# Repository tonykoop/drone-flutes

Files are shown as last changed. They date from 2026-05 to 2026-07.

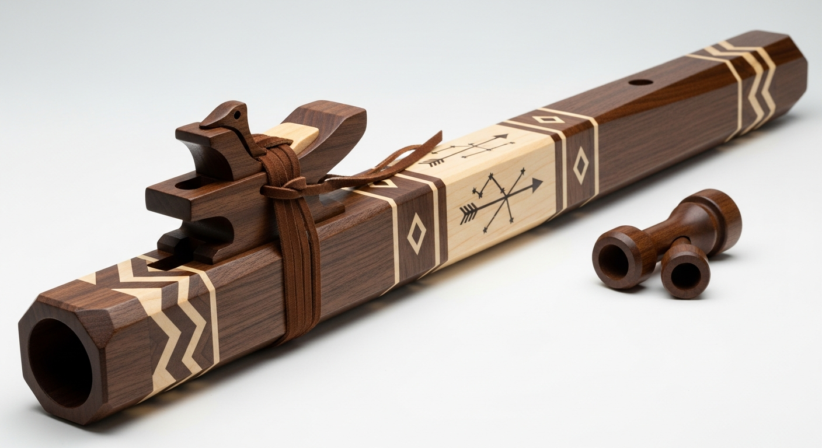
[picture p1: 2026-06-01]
images/hero-render.png

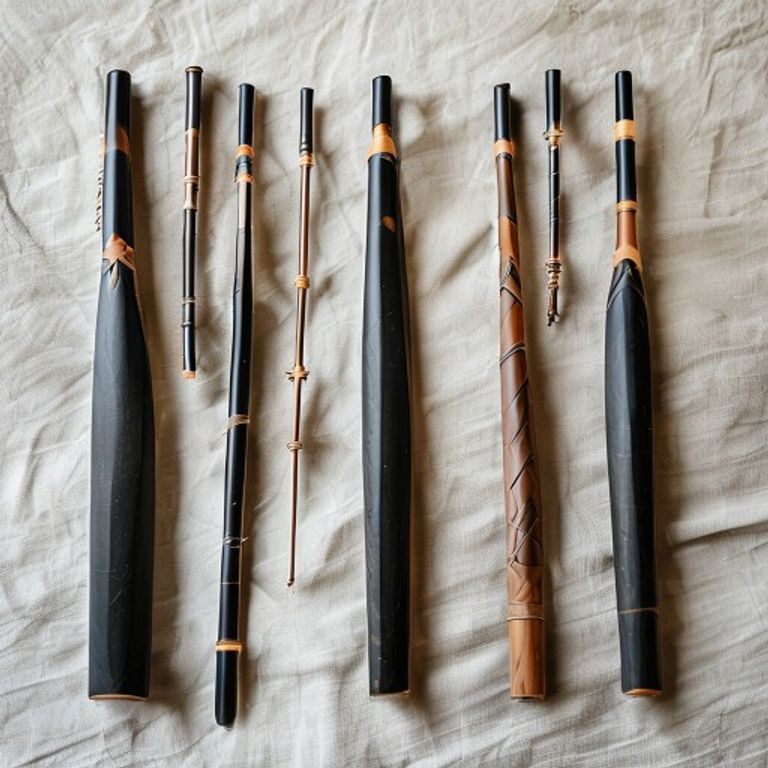
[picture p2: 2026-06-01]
images/family-group.png

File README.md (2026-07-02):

# Drone Flutes

A four-member family of Native American style drone flutes — Am, F#m, Em, Dm — built on Tony's open-pipe parametric design pipeline, with hybrid CNC + lathe + facet construction and Broinwood-style geometric CNC inlay in hard maple over walnut bodies. Each flute ships with three swappable drone blocks (unison, fifth-below, octave-below) so the player can change drone tuning without touching the melody side.

This is `DRN-FAM-001` in the catalog.

**Status:** L2 V5 build-packet candidate — DXF-first shop-handoff authority chain documented; acoustic body and drone-block DXF/CAD exports are still required before CNC routing (DXF-REV-001, FAB-BORE-009 blocked). All melody-tuning validation.csv rows are measurement-required pending first-article build.

> Aesthetic references: [Elemental Flutes gallery](https://elementalflutes.com/gallery) for the drone-flute form and [Broinwood](https://broinwood.com) for the inlay style. Engineering reference: the [`flutes`](https://github.com/tonykoop/flutes) repo for NAF K2 empirical corrections (150+ flute dataset).

Family overview

## What's in the box

```
.
├── Drone-Flutes-Design.xlsx           ← parametric source of truth (284 formulas)
├── Drone-Flutes-BOM-Build-Method.docx ← shop-floor build doc (v3-style companion)
├── design.md                          ← physics + family narrative
├── family-spec.csv                    ← row per family member, drives generators
├── bom.csv · sourcing.csv             ← what to buy, where, for how much
├── cut-list.csv · validation.csv      ← shop ops + tuning targets
├── dxf-shop-authority.md              ← DXF/CAD authority checklist and blockers
├── shop-validation-gates.csv          ← drone tuning, breath response, tolerance gates
├── visual-output-register.csv         ← drawing/inlay visual authority ledger
├── assembly-manual.md                 ← shop-floor cheat sheet
├── supplier-rfq.md                    ← 3 RFQ drafts ready to send
├── drawing-brief.md · visual-bom-brief.md
├── wolfram-starter.wl                 ← interactive Wolfram notebook
├── risks.md                           ← red-team failure-mode walk
├── capstone-deck.pptx                 ← recruiter / collaborator deck
├── print-packet.pdf                   ← shop-floor printable
├── site/index.html                    ← recruiter-facing static site
├── drawings/                          ← per-key SVG drawings + assembly + family-overview
├── inlay-patterns/{Am,Fsharpm,Em,Dm}/ ← 16 DXF + 16 SVG inlay patterns
├── sw-reference/                      ← SolidWorks master layout reference
├── cad/drone-flutes.scad              ← bore + tone-hole-schedule envelope master (pending_measurement; duct/fipple out of scope)
├── cnc/, images/, data/               ← placeholders for binary assets
├── evolution/                         ← Stage-0 evolution-pipeline intake (master manifest, design intent, revisions)
└── capstone-manifest.json             ← machine-readable manifest of everything above
```

## How it's built

1. **Excel `Master_Inputs` sheet** is the single edit surface for every dimension. Blue cells are inputs; black cells are formulas. Names match the SolidWorks global variables exactly.
2. **SolidWorks** reads from Excel via a linked design table (configurations: Am, F#m, Em, Dm). Master sketch on the Front plane drives every other sketch via convert-entities and pierce relations.
3. **CNC G-code** is generated in V-Carve from SolidWorks DXFs. Bore profile (1/4 downcut) → SAC pocket → splitting edge (1/16 upcut climb) → octagon facet pass (1/2 downcut, V-block jig) → inlay pockets (1/16 upcut) → finger holes (drill press, brad-point bits).
4. **Lathe** turns each glued blank to `body_OD_round` between centers; faceting then brings it to `body_OD_flat`.
5. **Drone blocks** are lathe-turned with a 0.75" tenon at 0.005" slip-fit clearance. Three blocks per flute (U / 5 / 8) for swappable drone tuning.

## DXF/shop authority boundary

The current repo has decorative inlay DXFs under `inlay-patterns/`, but no
released body, bore, finger-hole, SAC/window, drone-block, socket, or fixture
DXF/CAD files in the checkout. Use `dxf-shop-authority.md` as the shop handoff
checklist before cutting acoustic geometry. The inlay DXFs may guide decorative
inlay layout only; they do not control tuning, bore geometry, tone-hole
placement, breath response, drone-block fit, or flute-body tolerances.

## Family table

| Member | Key | f₀ (Hz) | bore_ID | L_total | Chamber:bore |
|---|---|---|---|---|---|
| DRN-Am  | Am  | 440.000 | 0.750" | 21.97 in | 20.4 |
| DRN-Fsm | F#m | 369.994 | 0.875" | 24.99 in | 21.0 |
| DRN-Em  | Em  | 329.628 | 1.000" | 27.23 in | 20.7 |
| DRN-Dm  | Dm  | 293.665 | 1.125" | 29.82 in | 20.8 |

All chamber:bore ratios sit in Tony's 17–21 sweet spot. Hole positions follow `pos_from_foot = L_acoustic_corrected × (1 − f₀/f_hole)` with K2 piecewise correction by bore size.

## Sister repos

This packet is part of Tony's open-pipe woodwind cluster. Cross-references:

- [`flutes`](https://github.com/tonykoop/flutes) — NAF family + K2 corrections (engineering reference)
- [`fujara`](https://github.com/tonykoop/fujara) — Slovak overtone flute (related physics)
- [`transverse-flute`](https://github.com/tonykoop/transverse-flute) — slip-cast transverse flute family
- [`shakuhachi`](https://github.com/tonykoop/shakuhachi)

For the cross-cluster catalog see `instrument-maker-v4` skill `references/repo-relationships.yaml`.

## Skill index used

- [instrument-maker-v4](https://...) — orchestrator + specialist sub-agents (acoustician, manufacturing-planner, documentarian, verifier, red-team)
- [xlsx](https://...) — Drone-Flutes-Design.xlsx
- [docx](https://...) — SolidWorks reference + BOM doc
- [pptx](https://...) — capstone-deck.pptx
- [pdf](https://...) — print-packet.pdf

## Roadmap

- [x] Excel design workbook with 284 formulas and 6 sheets
- [x] SolidWorks reference doc with global variables + design table setup
- [x] BOM + Build Method doc (v3-style companion)
- [x] CNC inlay patterns: 4 keys × 4 patterns × 2 formats = 32 files
- [x] v4 deliverables: design.md, family-spec, BOM/sourcing/cut/validation CSVs, assembly manual, RFQ, briefs, Wolfram starter, risks, capstone deck, print packet, site
- [ ] Build flute 1 (F#m) and tune-validate
- [ ] Update K2 corrections from measured data via `record_measurement.py`
- [ ] Photograph all 4 finished flutes for hero image
- [ ] Publish `site/` to GitHub Pages

## License

See [LICENSE](LICENSE).

## Contact

Tony Koop · tonykoop@gmail.com

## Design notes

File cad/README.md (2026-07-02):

# CAD Starter Notes

`drone-flutes.scad` is the first parametric master for this repo. Authority:
`pending_measurement` — see `visual-output-register.csv` CAD-001 and
`mcp-session-log.md`. No placeholder existed before this pass; there was no
`cad/` directory in the checkout prior to 2026-07-01.

Scope: melody-bore envelope, parallel drone-bore envelope, octagonal body
facet reference envelope, and the six pentatonic-minor tone-hole positions
(equation-driven from `design.md`'s governing model, the same way fret slots
are equation-driven elsewhere in this cluster). All four family members
(Am, F#m, Em, Dm) are selectable via the `member` parameter and each renders
clean in OpenSCAD.

Out of scope (per `dxf-shop-authority.md` and the woodwind addendum): SAC
chamber, splitting-edge/window profile, bird-block/flue-gap voicing, tone-hole
undercut/counterbore, and drone-socket tenon fit. These are hand-refined,
tuning-sensitive regions and are not modeled here — do not treat this master
as a substitute for the reviewed body/bore/tone-hole/drone-block DXF or CAD
exports that `dxf-shop-authority.md` still lists as missing (DXF-REV-001,
FAB-BORE-009 remain blocked).

Known open items carried in the header comment of the .scad itself:
- Melody-bore-to-drone-bore centerline offset is not in `family-spec.csv` or
  `design.md` — exposed as a top-level TBD/assumption parameter, not fact.
- Tone-hole diameter per member is inferred from `bom.csv` row 3.5's four
  brad-point sizes in ascending-bore order; the source row does not tag each
  size to a member, so treat this as an assumption pending review.

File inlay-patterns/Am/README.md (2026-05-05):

# Am drone flute — inlay artwork

Inlay files are sized to fit ONE facet of the Am flute. Eight identical bands wrap around the body (one per facet); the feature panel goes on a single chosen facet.

## Per-facet dimensions (this key)

| Item | Value |
|---|---|
| facet_side_length | 0.497 in |
| facet_inset | 0.100 in (each side) |
| inlay_band_width | 0.297 in |
| band_height | 0.500 in |
| feature_panel_width | 0.297 in |
| feature_panel_height | 7.029 in |
| L_total (full flute) | 21.967 in |

## Files

| File | Purpose | Pocket depth |
|---|---|---|
| `band1_chevron.svg` / `.dxf` | Lowest band (15% from foot) — chevron pattern | 0.060 in |
| `band2_chevron.svg` / `.dxf` | Center band (50%) — chevron pattern | 0.060 in |
| `band3_diamond.svg` / `.dxf` | Upper band (82%, just below bird) — diamond pattern | 0.060 in |
| `feature_constellation.svg` / `.dxf` | Feature panel (one facet, between band2 & band3) | 0.080 in |

Plug stock = 1/16" hard maple. Plug profile is the same DXF — V-Carve uses an inside offset of -0.001" for the pocket and outside offset of +0.0010" for the plug to create a 0.002" interference fit.

## DXF layers

- `POCKET_OUTLINE` — the rectangular pocket boundary (cut on profile pass)
- `CHEVRON` / `DIAMOND` / `STARS` / `ARROW` — engraved or cut-through detail lines
- `GUIDE` — visual reference only; do NOT machine

## Origin convention

DXFs anchor at (0,0) bottom-left so they import directly into V-Carve at the band y-offset given by Inlay_Layout sheet in the Excel workbook.

## CNC strategy

Use 1/16" upcut spiral. Spindle 18000 rpm, feed 60 ipm, plunge 20 ipm. Run pocket pass first; do plug profile cut on a separate fixture using maple stock.

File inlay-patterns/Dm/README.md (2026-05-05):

# Dm drone flute — inlay artwork

Inlay files are sized to fit ONE facet of the Dm flute. Eight identical bands wrap around the body (one per facet); the feature panel goes on a single chosen facet.

## Per-facet dimensions (this key)

| Item | Value |
|---|---|
| facet_side_length | 0.652 in |
| facet_inset | 0.100 in (each side) |
| inlay_band_width | 0.452 in |
| band_height | 0.500 in |
| feature_panel_width | 0.452 in |
| feature_panel_height | 9.544 in |
| L_total (full flute) | 29.824 in |

## Files

| File | Purpose | Pocket depth |
|---|---|---|
| `band1_chevron.svg` / `.dxf` | Lowest band (15% from foot) — chevron pattern | 0.060 in |
| `band2_chevron.svg` / `.dxf` | Center band (50%) — chevron pattern | 0.060 in |
| `band3_diamond.svg` / `.dxf` | Upper band (82%, just below bird) — diamond pattern | 0.060 in |
| `feature_constellation.svg` / `.dxf` | Feature panel (one facet, between band2 & band3) | 0.080 in |

Plug stock = 1/16" hard maple. Plug profile is the same DXF — V-Carve uses an inside offset of -0.001" for the pocket and outside offset of +0.0010" for the plug to create a 0.002" interference fit.

## DXF layers

- `POCKET_OUTLINE` — the rectangular pocket boundary (cut on profile pass)
- `CHEVRON` / `DIAMOND` / `STARS` / `ARROW` — engraved or cut-through detail lines
- `GUIDE` — visual reference only; do NOT machine

## Origin convention

DXFs anchor at (0,0) bottom-left so they import directly into V-Carve at the band y-offset given by Inlay_Layout sheet in the Excel workbook.

## CNC strategy

Use 1/16" upcut spiral. Spindle 18000 rpm, feed 60 ipm, plunge 20 ipm. Run pocket pass first; do plug profile cut on a separate fixture using maple stock.

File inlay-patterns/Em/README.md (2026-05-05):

# Em drone flute — inlay artwork

Inlay files are sized to fit ONE facet of the Em flute. Eight identical bands wrap around the body (one per facet); the feature panel goes on a single chosen facet.

## Per-facet dimensions (this key)

| Item | Value |
|---|---|
| facet_side_length | 0.601 in |
| facet_inset | 0.100 in (each side) |
| inlay_band_width | 0.401 in |
| band_height | 0.500 in |
| feature_panel_width | 0.401 in |
| feature_panel_height | 8.712 in |
| L_total (full flute) | 27.225 in |

## Files

| File | Purpose | Pocket depth |
|---|---|---|
| `band1_chevron.svg` / `.dxf` | Lowest band (15% from foot) — chevron pattern | 0.060 in |
| `band2_chevron.svg` / `.dxf` | Center band (50%) — chevron pattern | 0.060 in |
| `band3_diamond.svg` / `.dxf` | Upper band (82%, just below bird) — diamond pattern | 0.060 in |
| `feature_constellation.svg` / `.dxf` | Feature panel (one facet, between band2 & band3) | 0.080 in |

Plug stock = 1/16" hard maple. Plug profile is the same DXF — V-Carve uses an inside offset of -0.001" for the pocket and outside offset of +0.0010" for the plug to create a 0.002" interference fit.

## DXF layers

- `POCKET_OUTLINE` — the rectangular pocket boundary (cut on profile pass)
- `CHEVRON` / `DIAMOND` / `STARS` / `ARROW` — engraved or cut-through detail lines
- `GUIDE` — visual reference only; do NOT machine

## Origin convention

DXFs anchor at (0,0) bottom-left so they import directly into V-Carve at the band y-offset given by Inlay_Layout sheet in the Excel workbook.

## CNC strategy

Use 1/16" upcut spiral. Spindle 18000 rpm, feed 60 ipm, plunge 20 ipm. Run pocket pass first; do plug profile cut on a separate fixture using maple stock.

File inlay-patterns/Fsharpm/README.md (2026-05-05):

# F#m drone flute — inlay artwork

Inlay files are sized to fit ONE facet of the F#m flute. Eight identical bands wrap around the body (one per facet); the feature panel goes on a single chosen facet.

## Per-facet dimensions (this key)

| Item | Value |
|---|---|
| facet_side_length | 0.549 in |
| facet_inset | 0.100 in (each side) |
| inlay_band_width | 0.349 in |
| band_height | 0.500 in |
| feature_panel_width | 0.349 in |
| feature_panel_height | 7.996 in |
| L_total (full flute) | 24.987 in |

## Files

| File | Purpose | Pocket depth |
|---|---|---|
| `band1_chevron.svg` / `.dxf` | Lowest band (15% from foot) — chevron pattern | 0.060 in |
| `band2_chevron.svg` / `.dxf` | Center band (50%) — chevron pattern | 0.060 in |
| `band3_diamond.svg` / `.dxf` | Upper band (82%, just below bird) — diamond pattern | 0.060 in |
| `feature_constellation.svg` / `.dxf` | Feature panel (one facet, between band2 & band3) | 0.080 in |

Plug stock = 1/16" hard maple. Plug profile is the same DXF — V-Carve uses an inside offset of -0.001" for the pocket and outside offset of +0.0010" for the plug to create a 0.002" interference fit.

## DXF layers

- `POCKET_OUTLINE` — the rectangular pocket boundary (cut on profile pass)
- `CHEVRON` / `DIAMOND` / `STARS` / `ARROW` — engraved or cut-through detail lines
- `GUIDE` — visual reference only; do NOT machine

## Origin convention

DXFs anchor at (0,0) bottom-left so they import directly into V-Carve at the band y-offset given by Inlay_Layout sheet in the Excel workbook.

## CNC strategy

Use 1/16" upcut spiral. Spindle 18000 rpm, feed 60 ipm, plunge 20 ipm. Run pocket pass first; do plug profile cut on a separate fixture using maple stock.

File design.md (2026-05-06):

# Drone Flute Family — Parametric Design (v4)

**Packet:** DRN-FAM-001
**Family:** open-pipe (Native American Flute lineage; drone-flute variant)
**Pipeline:** cnc-lathe (hybrid: split-body CNC + lathe round + CNC facet)
**Status:** in-progress
**Sisters:** [flutes](https://github.com/tonykoop/flutes), [fujara](https://github.com/tonykoop/fujara), [transverse-flute](https://github.com/tonykoop/transverse-flute), [shakuhachi](https://github.com/tonykoop/shakuhachi)
**Done-bar reference:** `flutes` (NAF family with K2 corrections)
**Aesthetic references:** elementalflutes.com/gallery, broinwood.com (CNC inlay)
**Date:** 2026-05-05

## What this is

A four-member family of Native American style **drone flutes** (each flute has both a melodic side and a separate sustained-drone chamber sharing the same body). Keys: Am, F#m, Em, Dm. Bodies are walnut, inlay is hard maple. The drone block is **swappable** — three blocks ship per flute (unison, perfect fifth below, octave below) so the player can change the drone without retuning the melody side.

This is the same parametric workflow Tony uses for the rest of the open-pipe woodwinds (`flutes`, `fujara`, `transverse-flute`): an Excel `Master_Inputs` sheet with named global variables drives the `Design_Table`; SolidWorks reads from the same Excel via a linked design table; CNC G-code is generated in V-Carve from SolidWorks-exported DXFs.

## Governing model

Open-open pipe with end corrections and Tony's empirical NAF K2 bore-size correction.

```
f = c / (2 · L_eff)
L_eff = L_acoustic_corrected = (c / (2 · f)) · (1 + K2(bore_ID))
L_bore_physical = L_acoustic_corrected − 2 · k_end · (bore_ID / 2)
```

- `c` = 13,552 in/s at 68°F
- `k_end` = 0.6 (open-end correction multiplier, applied at each open end)
- `K2(bore_ID)` is a piecewise lookup: −2.0 % for bore < 0.75 in, −0.7 % for 0.75–0.875, +0.4 % for 0.875–1.0, +0.7 % for 1.0–1.125, +1.3 % for ≥ 1.125 in. Source: 150+ NAF measurements (Tony's empirical dataset).

Hole positions (from foot, m3 closest to foot, octave farthest):

```
pos_from_foot = L_acoustic_corrected · (1 − f_fundamental / f_hole)
```

Pentatonic minor scale (NAF Mode 1/4): semitone offsets `[+3, +5, +7, +8, +10, +12]` from the fundamental.

The drone chamber is a separate parallel bore in the same body; it has its own `bore_ID`, its own K2 correction, and its own `L_acoustic`. The drone block tenon-fits into a socket at the foot end; three blocks per flute provide unison / fifth-below / octave-below tunings via different cavity lengths.

## Family scaling law

For a given pitch class (minor) and same drone-offset configuration, all member dimensions follow the open-pipe relationship `L ∝ 1/f`. Choosing bore_ID per key keeps the chamber-to-bore ratio inside Tony's 17–21 sweet spot (denser air column for lower keys, narrower bore for higher keys).

| Member | Key | Fund. (Hz) | Bore ID | L_total | Chamber:bore |
|---|---|---|---|---|---|
| DRN-Am  | Am  | 440.0 | 0.750" | 21.97 in | 20.4 |
| DRN-Fsm | F#m | 370.0 | 0.875" | 24.99 in | 21.0 |
| DRN-Em  | Em  | 329.6 | 1.000" | 27.23 in | 20.7 |
| DRN-Dm  | Dm  | 293.7 | 1.125" | 29.82 in | 20.8 |

See `family-spec.csv` for the row-per-member spec the auto-generators read.

## Parametric design surface

Source of truth for all numbers: **`Drone-Flutes-Design.xlsx`** (Master_Inputs sheet). Blue cells are user-editable inputs; black cells are formulas. SolidWorks reads from the Design_Table sheet via the linked design table — see `sw-reference/Drone-Flutes-SolidWorks-MasterLayout.docx`.

Key inputs (edit these to retarget the family):

- `c_speed_of_sound` (in/s) — adjust for shop temperature
- `A4_reference` (Hz) — concert pitch; 440 by default, can change to 432
- `MIDI_note` per column — defines each member's fundamental
- `bore_ID` per column — drives K2 and chamber:bore ratio
- `drone_offset_st` — global; flips all four flutes between unison/5th/octave drones
- `n_facets` — octagon by default; can change to hex (6) or dodecagon (12)
- Inlay parameters — band positions, depths, plug oversize

## Construction summary

Hybrid build:

1. **Split-body CNC** — bandsaw the blank in half along the long axis, route the bore profile and SAC pocket on each half, glue back. This is the only practical way to put a precision bore in a long blank with the ShopBot.
2. **Lathe rounding** — turn glued blank to `body_OD_round` (which includes a `facet_allowance` for the next step).
3. **CNC faceting** — V-block jig, eight 22.5° rotations, flatten each facet on the ShopBot to bring `body_OD_flat` to spec. This produces eight flat faces for inlay.
4. **CNC inlay** — chevron (band 1, 2), diamond (band 3), constellation+arrow (feature panel) per `inlay-patterns/{key}/`.
5. **Drone block set** — three lathe-turned blocks per flute (unison/5/8). Tenon engagement length 0.75", 0.005" slip-fit clearance.

## Validation strategy

Each finished flute is tuned with a chromatic tuner against the predicted frequencies in `validation.csv`. Cents error is recorded; deviations >5 cents trigger a hole-recutting decision (file the foot edge to lower, fill the bird edge to raise). Measured data feeds back into `validation.csv` and through `record_measurement.py` into Tony's per-family corrections database (eventually).

## Open assumptions

- A=440 reference. Change `A4_reference` for 432 or HIPP tunings.
- 68°F shop reference. The walnut-glue cure window assumes this.
- Octagon (8 facets). The same workbook supports 6 or 12 by changing `n_facets`.
- Walnut + maple as the wood pair. `Wood_Library` sheet lists alternates with E, ρ, Janka.
- Single concert-pitch tuning for all four flutes. Could split-tune (e.g., F#m and Dm at A=440 for solo, Em and Am at A=432 for ensemble work).

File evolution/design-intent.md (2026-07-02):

# Design Intent — drone-flutes rev A

- Master CAD: `cad/drone-flutes.scad` (sha256: 05f84ff9b06209cb90c3cb4582ba9f86a4075b30f41d5fecbc404bded7124ddd), driven by `family-spec.csv` (sha256: 1cfbed45703db40fa902f2bde1a24349374f9bfefdf9ba2f1b1fe5c1240d1253) and `Drone-Flutes-Design.xlsx` (sha256: d3b784c738a0f81cb7581b918f8eaa2f04b11650797b9905257d2063148a2dca)
- Function: A four-member family of Native American style drone flutes (Am, F#m, Em, Dm) — hybrid CNC + lathe + facet construction, hard maple inlay over walnut bodies. Each flute has a melody bore (open-open pipe, six pentatonic-minor finger holes) and a separate parallel drone chamber fed by one of three swappable tenon-fit drone blocks (unison / fifth-below / octave-below), so drone tuning can change without retuning the melody side.
- Environment: player-breath-driven open-pipe woodwind; walnut body is a solid-wood plate/tube assembly sensitive to humidity and glue-line integrity (risks.md S-1). Shop reference temperature 68°F (design.md).
- Target qty: 1 prototype (F#m first article per roadmap). Deadline: TBD. Budget/unit ceiling: TBD.

## Critical dimensions (carry tolerances)

| Feature | Nominal | Tolerance | Why critical | Source |
| --- | --- | --- | --- | --- |
| Bore ID (per member) | 0.750–1.125 in (Am→Dm) | drives K2 correction + chamber:bore ratio | governs fundamental pitch and voicing | family-spec.csv `bore_id_in` (measurement_required) |
| Total length (per member) | 21.97–29.82 in (Am→Dm) | body blank sizing | acoustic length sets fundamental | family-spec.csv `total_length_in` (measurement_required) |
| Tone-hole positions (6, pentatonic minor) | formula-driven, e.g. Am H1≈2.43 in from foot | drawing-brief.md: hole positions ±0.020 in | melody-side intonation | design.md governing model `pos_from_foot = L_acoustic·(1−f0/f_hole)`, cad/drone-flutes.scad echo check |
| Drone bore ID (per member) | 0.625–1.000 in (Am→Dm) | measurement_required | drone-side pitch/voicing | family-spec.csv `drone_bore_in` |
| Body OD / facet side (per member) | body_od 1.300–1.675 in; facet_side 0.497–0.652 in | shop tolerances ±0.030 in (drawing-brief.md) | wall thickness after faceting | family-spec.csv `body_od_in`, `facet_side_in` |
| Wall thickness at bore, post-facet | ≥0.20 in structural minimum | caliper check after CNC facet | crack risk if thinner (risks.md S-3) | risks.md S-3 |
| Drone-block tenon engagement / slip fit | 0.75 in engagement, 0.005 in clearance | ±0.003 in fit-critical (drawing-brief.md) | swap reliability, breakage risk (risks.md S-2) | shop-validation-gates.csv FAB-TENON-007 |
| Bore-to-bore (melody/drone) centerline offset | TBD | n/a — not yet sourced | needed for split-body CNC toolpath | NOT in family-spec.csv or design.md; exposed as `bore_offset_in` assumption in cad/drone-flutes.scad, flagged for review |

## Incidental (free for DFM)

- Octagon facet count could vary (workbook `n_facets` supports 6/8/12); inlay band/plug artwork and layout; wood species substitution within `Wood_Library` sheet alternates; bird-block/leather-lace cosmetic detail.

## Must-nots (DFM may never violate)

- Do not cut acoustic body/bore/tone-hole/drone-block geometry from anything but a reviewed CAD/DXF export matching the current workbook revision (dxf-shop-authority.md; DXF-REV-001 gate, currently blocked).
- Do not use a decorative inlay DXF to infer body length, hole location, bore geometry, drone-block cavity length, or fixture datums (dxf-shop-authority.md "Decorative Inlay Boundary").
- Do not reduce wall thickness below the 0.20 in structural minimum without recomputing crack risk (risks.md S-3).
- Do not treat `cad/drone-flutes.scad`'s tone-hole diameters or bore-to-bore offset as fabrication fact — both are explicitly flagged assumption/TBD in the file header pending a sourced value.
- Do not skip the chisel finishing pass on the splitting edge — leaving the upcut skin unfinished causes breathy tone (risks.md A-3); this geometry is out of scope for the .scad by design.

## Material intent

- Preferred: black walnut body, hard maple inlay (bom.csv rows 1.1–1.4). Tru-Oil + Howards Feed-N-Wax finish.
- Acceptable subs: cherry or mahogany for body walnut; curly maple or holly for inlay (sourcing.csv substitute_acceptable column).
- Forbidden: none recorded.

## Stage status

Stage 0 intake complete 2026-07-01. Gate A (Alpha shop compile) NOT yet run — no concessions logged, nothing presented as shippable. dxf-shop-authority.md's acoustic-body DXF/CAD export gate (DXF-REV-001) and FAB-BORE-009 remain blocked independent of this intake.

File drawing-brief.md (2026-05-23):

# Drawing Brief — Drone Flute Family

Quality bar: Fender Stratocaster blueprint level. Drawings live in `drawings/`. Generated by `scripts/generate_drawings.py` v4 (or hand-built for the initial set — see `drawings/build_drawings.py` in this repo).

## Current authority status

The checked-in `drawings/*.svg` files are review previews, not released shop
authority. No body, bore, finger-hole, SAC/window, drone-block, socket, fixture,
or CAM-ready DXF/CAD export is present in the repo as of the Round 33C/D shop
handoff slice.

Decorative DXFs under `inlay-patterns/` are separated from acoustic and core
fabrication authority. They may be used for decorative pocket/plug planning
after a facet datum is confirmed, but they do not control bore length, hole
placement, window geometry, drone-block tuning, or body fit.

See `dxf-shop-authority.md` and `visual-output-register.csv` before treating
any visual or DXF artifact as shop evidence.

## Per-member drawings

One SVG per family member, plus one shared assembly drawing.

### `drawings/{member}.svg` (4 files)

Single-page tabloid (11×17) layout. Sections:

1. **Title block (bottom right)** — instrument name, member ID, key, date (2026-05-05), revision (R0), units (inches), scale (1:2), source workbook, source CAD, drawn-by.
2. **Plan view** — flute lying on its side, bird block on top facet, full length visible. Show window position, all 6 finger holes with diameters, foot end, drone socket.
3. **Side view** — rotated 45°, shows the octagonal cross-section in projection.
4. **Section A-A** — through-bore axial section. Bore ID, wall thickness, SAC chamber, splitting edge wall.
5. **Section B-B** — radial section through the body, showing octagonal facets and bore.
6. **Hole schedule callout** — small table inset listing each hole's distance from foot, diameter, undercut angle.
7. **Datum chain** — primary datum at FOOT (open end), secondary at WINDOW (splitting edge), tertiary at SOCKET (drone block face).
8. **Tolerances** — tuning-critical (hole positions ±0.020"), fit-critical (drone tenon ±0.003"), shop tolerances (everything else ±0.030").

### `drawings/assembly.svg` (1 file)

Exploded view of one flute (use F#m as the canonical) with callouts for body, bird block, leather lace, drone block set (3 blocks fanned).

### `drawings/family-overview.svg` (1 file)

All 4 flutes in plan view side-by-side, scaled to a common foot datum. Shows the proportional relationship between keys.

## Generation method

For now, hand-built via `drawings/build_drawings.py` in this repo. When v4's `generate_drawings.py` becomes the canonical tool, switch to it.

## Cross-reference table

Each critical dimension on each drawing must trace back to one of:
- A formula in `Drone-Flutes-Design.xlsx` (cite as `=Master_Inputs!B7` or similar).
- A row in `family-spec.csv`.
- An assumption explicitly noted on the drawing (e.g., "facet inset 0.10" — assumed").

## Reviewers

- Tony (final accept).
- Maker Nexus shop staff (CNC/lathe feasibility check).

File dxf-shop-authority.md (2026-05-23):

# DXF-First Shop Authority Checklist

Current status: DXF-first shop handoff checklist; acoustic fabrication authority
is not released.

Issue #1 asks this packet to move toward a validated shop handoff while keeping
decorative inlay assets separate from acoustic and fabrication authority. This
file names what exists and what must exist before a maker cuts acoustic
geometry.

## Current Authority Inventory

| Artifact | Current status | Authority boundary |
| --- | --- | --- |
| `Drone-Flutes-Design.xlsx` | parametric design source | Governs formulas and design intent, but does not replace exported/reviewed shop DXF/CAD. |
| `sw-reference/Drone-Flutes-SolidWorks-MasterLayout.docx` | SolidWorks setup reference | Reference for rebuilding CAD; not a checked-in CAD model or CAM export. |
| `drawings/*.svg` | preview drawings | Review previews only; not CNC, router, drill, lathe, or inspection authority. |
| `inlay-patterns/*/*.dxf` | decorative inlay artwork | Decorative pocket/plug geometry only after body facet datum is proven; not acoustic authority. |
| Body/bore/tone-hole DXF or CAD | missing | Required before acoustic body CNC routing. |
| Drone-block/socket DXF or CAD | missing | Required before batch machining swappable drone blocks. |
| Fixture/V-block DXF or CAD | missing | Required before repeatable facet indexing and inlay registration. |

## Required Shop-Authority Exports

Create or name the following before releasing this as a validated DXF-first
shop packet:

| Required export | Must control | Source trace |
| --- | --- | --- |
| `cad/DRN-*-body-bore.dxf` or equivalent CAD | split-body bore, SAC chamber, window/splitting edge, open-foot datum | `Drone-Flutes-Design.xlsx`, `family-spec.csv`, reviewed CAD model |
| `cad/DRN-*-toneholes.dxf` | six tone-hole centers, diameters, undercut/counterbore notes, foot datum chain | workbook hole formulas plus first-article tuning correction |
| `cad/DRN-*-drone-blocks.dxf` or turned-part drawing | unison, fifth-below, octave-below block cavity lengths and tenon fit | workbook/drone tuning table plus measured swap response |
| `cad/fixture-vblock-indexing.dxf` | V-block angle, stop datum, rotation/indexing features, clamp clearance | body OD/facet data plus shop workholding review |
| `cnc/README.md` or setup sheet | tool sequence, stock datum, cutter list, feeds/speeds source, go/no-go checks | reviewed CAD/DXF revision and shop profile |

## Go/No-Go Checks

- Go only when all acoustic and fit-critical DXF/CAD exports name the same
  workbook revision and member configuration.
- Go only after first-article flute data records fundamental, six melody notes,
  and all three drone-block modes in `validation.csv` or
  `shop-validation-gates.csv`.
- Go only after breath-response notes record onset, choking, air noise, and
  stable tone behavior for the SAC/window/bird setup.
- Go only after tenon/socket slip fit and facet-indexing checks pass on scrap
  or the first article.
- Stop if a decorative inlay DXF is being used to infer flute-body dimensions,
  hole locations, bore geometry, drone-block cavity length, or fixture datums.

## Decorative Inlay Boundary

The inlay DXFs are useful shop assets for aesthetic pockets and plugs, but they
are downstream of the acoustic body. Place them after the body datum, facet
width, and member length are confirmed from authority geometry. Do not let an
inlay pattern become the source of body length, facet size, tone-hole position,
or drone-block fit.

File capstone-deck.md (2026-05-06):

# Drone Flute Family — Capstone Deck

Slide-by-slide outline. Renders to `capstone-deck.pptx` via `python-pptx`.

# Title

Drone Flute Family · DRN-FAM-001
Walnut + Maple · 4 keys · Tunable drone block set
Tony Koop · Maker Nexus · 2026-05-05

# Project Intent

A four-member family of Native American style drone flutes (Am, F#m, Em, Dm) inspired by elementalflutes.com gallery. Each flute has a separate drone chamber with three swappable drone blocks (unison, fifth, octave). Goal: ship a publishable build packet that another maker could rebuild from these files.

# File Map

- `Drone-Flutes-Design.xlsx` — parametric source of truth (284 formulas, 6 sheets)
- `design.md` — physics + family scaling write-up
- `bom.csv` / `sourcing.csv` / `cut-list.csv` / `validation.csv` — structured data
- `assembly-manual.md` / `supplier-rfq.md` / `visual-bom-brief.md` / `drawing-brief.md` — markdown briefs
- `risks.md` — red-team failure-mode walk
- `wolfram-starter.wl` — interactive Wolfram notebook
- `drawings/` — 4 dimensioned SVG drawings + assembly + family-overview
- `inlay-patterns/` — 16 DXF + 16 SVG inlay patterns (4 per key × 4 keys)
- `sw-reference/` — SolidWorks master layout reference
- `site/` — recruiter-facing static site

# Build Workflow

design (Excel + SW) → source (BOM/sourcing/RFQ) → cut (cut-list) → fixture (V-block jig) → split-body CNC → glue → lathe → facet → holes → window → inlay → drone blocks → bird → finish → tune → validate

# Design Sheet Highlights

- A4 = 440 Hz reference; switchable to 432 in one cell.
- K2 piecewise correction by bore ID; 5 segments from −2.0 % to +1.3 %.
- Chamber:bore ratio held in 17–21 across all keys (Am 20.4, F#m 21.0, Em 20.7, Dm 20.8).
- Drone offset is a global semitone variable; flips all 4 flutes between U / 5 / 8 in one edit.

# BOM Snapshot

Material total: $193 walnut + maple. Tooling total: $245 (one-time). Hardware/finish: $78. Grand total: $516 for the family.

Walnut bodies (4) + drone block stock (12 from 1 stick) + maple inlay (3 sheets) + finish (Tru-Oil + carnauba) + 6 CNC bits + 8 drill/Forstner.

# Drawings · CAD · CNC

Per-member SVG drawings in `drawings/{Am,Fsm,Em,Dm}.svg` — title block, plan + side + section views, datum chain (foot → window → drone socket), tolerance bands. Family-overview SVG shows all 4 to scale.

CNC G-code is generated in V-Carve from SolidWorks DXFs. ShopBot toolpaths: bore profile (1/4 downcut), facet (1/2 downcut), inlay (1/16 upcut), splitting edge (1/16 upcut climb cut).

# Visual BOM

`images/visual-bom.png` — 11×17 plate, hero + spreadsheet + sub-assembly callouts. Reference: ashiko-drum-workshop visual BOM.

# Assembly Manual Quick Reference

12 phases, 8-week calendar:
- Wk 1: stock prep + acclimation
- Wk 2: split-body CNC + glue
- Wk 3: lathe + faceting + holes + window
- Wk 4: inlay (24 ops/flute)
- Wk 5: drone blocks (12 total) + birds
- Wk 6: finish (Tru-Oil)
- Wk 7: cure
- Wk 8: tune + validate + photos

# Validation

Per-flute, per-note tuning checked vs `validation.csv` predictions. Pass band: ±5 cents. Drone chamber tested as independent (A-2 risk). Wall thickness verified ≥ 0.20" structural minimum.

# Open Risks

Top 3 from `risks.md`:
- A-1: Hole 6 (octave) prone to running sharp
- A-2: Drone-melody chamber leak (high severity, glue-up critical)
- E-1: Em/Dm hand reach for 5th-percentile players

# Next Actions

1. Order BOM (RFQ drafts ready in `supplier-rfq.md`).
2. Acclimate walnut blanks 7 days before machining.
3. Generate finalized G-code from SolidWorks design table after blanks arrive.
4. Build, tune, photograph.
5. Record measurements through `record_measurement.py` to feed the per-family corrections.

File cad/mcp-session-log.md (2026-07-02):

# MCP / External-Tool Session Log

V5 provenance record for artifacts generated or modified by external tools.
Required before claiming any artifact came from OpenSCAD, Blender, Illustrator,
Photoshop, Fusion, SketchUp, or similar tooling.

| session_id | tool | input_authority | outputs | role | authority_result | review_status | notes |
|---|---|---|---|---|---|---|---|
| fable-v5-refresh-2026-07-01 | claude-code (Fable 5) | Drone-Flutes-Design.xlsx, family-spec.csv | bom.csv, sourcing.csv, cut-list.csv, validation.csv, shop-validation-gates.csv, family-spec.csv, Drone-Flutes-Design.xlsx | packet_refresh | fabrication | self_checked | V5 refresh pass: tabular packet data reviewed against family-spec.csv / design table baseline; no dimension changes made. Provenance rows added to satisfy V5 fabrication-artifact logging. |
| fable-v5-refresh-2026-07-01 | claude-code (Fable 5) + OpenSCAD CLI | family-spec.csv, design.md, drone-flutes-starter.wl (formula mirror), bom.csv row 3.5 | cad/drone-flutes.scad | cad_authoring | pending_measurement | self_checked | First parametric master for this repo: melody-bore + drone-bore + octagon body/facet envelope, equation-driven pentatonic-minor tone-hole schedule (design.md hole formula). Duct/fipple/window/voicing geometry explicitly out of scope (see header). Bore-to-bore offset flagged TBD/assumption — not in any source table. Tone-hole diameter per member is an ascending-bore-order assumption from bom.csv row 3.5 (brad-point set not member-tagged in source). OpenSCAD render check: pass for all 4 members (openscad -o STL, exit 0). |
| fable-v5-refresh-2026-07-01 | claude-code (Fable 5) | Drone-Flutes-Design.xlsx (Master_Inputs mirror) | drone-flutes-starter.wl | analysis_source | derived_preview | unreviewed | Pre-existing Wolfram source, deployed read-only to Wolfram Cloud (Public-Execute) and embedded live in explorer.html. Not re-executed or modified this pass — source-only, L2 evidence. Register row added (WL-001). |

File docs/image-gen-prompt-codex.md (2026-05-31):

# Image Generation Prompt

Concept visualization only. Do not treat generated images as dimensional, tuning, CAD, DXF, or fabrication authority.

## Hero Prompt

Photorealistic studio product photograph of a finished Native American style drone flute family member, walnut body with eight flat facets, hard maple geometric CNC inlay bands, two parallel chambers for melody and drone, six melody finger holes, a removable external bird block over the slow-air chamber, and three swappable drone blocks arranged beside the flute. Clean studio background, warm oiled walnut and pale maple contrast, realistic scale cues, soft directional studio lighting, three-quarter product-photography angle, about a 50mm lens, high detail, photorealistic.

## In-Context Prompt

Photorealistic image of a player seated in a quiet acoustic room holding the drone flute horizontally, fingers naturally covering the melody holes while the drone side runs parallel. A small tray nearby holds alternate drone blocks labeled only by shape, not readable text. Natural window light, calm performance setting, the walnut-and-maple inlay visible without exaggeration, environmental storytelling around a handcrafted tuned flute.

## Detail/Macro Prompt

Close-up macro of the drone flute bird block and inlay: removable carved wooden block seated over the slow-air chamber, crisp flue track shadow, maple chevron or diamond inlay set into faceted walnut, clean socket for a swappable drone block, polished finish, photorealistic texture and shallow depth of field.

## Negative / Avoid

Avoid sacred/cultural caricature, logos, watermarks, unreadable fake text, extra holes, impossible double mouths, floating blocks, distorted hands, and dimensions presented as fabrication evidence.

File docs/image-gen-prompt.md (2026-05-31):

# Image-Gen Prompts

Concept image only; not fabrication authority. Do not include cut-ready dimensions, hole locations, or toolpaths.

## Hero Prompt

A single finished Native American style drone flute photographed as a real physical object, lying on its side at a three-quarter product-photography angle, ~50mm lens. The body is solid black walnut with a deep chocolate grain, machined into a faceted octagonal cross-section that runs the full length of the long, slender pipe. A separate bird block sits saddled across the top facet, lashed down with a thin natural leather lace. The two open ends of the open-open pipe are clearly visible. Geometric Broinwood-style inlay in pale hard maple is set flush into the flat facets — chevron bands near the ends, a diamond band mid-body, and a constellation-and-arrow feature panel — bright maple against dark walnut. At the foot end, a turned drone block with a round tenon plugs into a socket, and two additional swappable drone blocks rest just behind it. Hand-rubbed satin oil finish, soft wood sheen. Clean neutral studio background, soft directional studio light, realistic scale cues suggesting an arm's-length instrument, high detail, photorealistic, no text labels.

## In-Context Prompt

The same faceted walnut-and-maple drone flute staged in a warm woodworking shop on a linen drop, bird block lashed on top, with its three swappable drone blocks fanned out in front. Natural window light raking across the octagonal facets and lighting the pale maple inlay against the dark walnut. Wood shavings, a few hand tools, and a softly blurred lathe in the background tell the maker's-bench story. Shallow depth of field, environmental storytelling, concept visualization only, no text.

## Detail Prompt

Macro close-up of the signature octagonal-facet body with flush geometric maple inlay set into black walnut — sharp chevron and diamond bands and the constellation-and-arrow feature panel, the crisp angled edges where flat facets meet, and the swappable drone block's turned tenon entering its socket at the foot. Raking light to bring out tool-crisp facet edges, the contrast between bright hard maple and dark walnut grain, and the satin oil finish. High detail, photorealistic, no measurements.

## Negative / Avoid

No text/logos/watermarks/fake maker marks, no dimension callouts or measurement lines, no impossible mechanisms or floating parts, no rounded one-piece round body (it is faceted/octagonal), no holes drilled into the inlay; anatomically plausible hands if a player is shown.

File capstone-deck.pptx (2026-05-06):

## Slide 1

DRONE
FLUTE
FAMILY

DRN-FAM-001

Native American style

Four flutes · Walnut + Maple
Tunable drone block set

F#m · Em · Dm · Am

Tony Koop · Maker Nexus, South Bay · 2026-05-05

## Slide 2

Project Intent

What this project is, why it exists, who it's for.

A four-member family of Native American drone flutes (Am, F#m, Em, Dm). Walnut bodies with hard maple CNC inlay. Each flute ships with three swappable drone blocks — unison, fifth-below, octave-below — so the player can change drone tuning without touching the melody side.

Build it once. Tune it forever.
Inspired by elementalflutes.com gallery (drone form) and broinwood.com (CNC inlay style). Engineering reference: tonykoop/flutes — NAF K2 empirical corrections from 150+ measured flutes.

members
(Am · F#m · Em · Dm)

4

drone blocks per flute
(unison · 5th · octave)

3

facets per body
(octagonal CNC inlay)

8

DRN-FAM-001 · Tony Koop · Maker Nexus · 2026-05-05

2 / 14

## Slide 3

File Map

Every artifact in this packet.

PARAMETRIC SOURCE

STRUCTURED DATA

RECRUITER-FACING

- Drone-Flutes-Design.xlsx — 6 sheets, 284 formulas
- design.md — physics + family narrative
- family-spec.csv — auto-generator input
- wolfram-starter.wl — interactive notebook
- sw-reference/Drone-Flutes-SolidWorks-MasterLayout.docx

- bom.csv · sourcing.csv
- cut-list.csv · validation.csv
- supplier-rfq.md (3 RFQ drafts)
- drawing-brief.md · visual-bom-brief.md
- risks.md (red-team failure-mode walk)

- capstone-deck.pptx (this deck)
- print-packet.pdf (shop floor)
- site/index.html (build-log site)
- drawings/*.svg (4 keys + assembly + family)
- inlay-patterns/ (16 DXF + 16 SVG)

DRN-FAM-001 · Tony Koop · Maker Nexus · 2026-05-05

3 / 14

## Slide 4

Build Workflow

Twelve phases over eight weeks.

Stock prep

Split-body CNC

Glue-up

Lathe round

1

2

3

4

CNC facet

Tone holes

Window/edge

CNC inlay

5

6

7

8

Drone blocks

9

Bird block

10

Finish

11

Tune + QA

12

Weeks 1–7 hands-on; week 8 cure + tune. Calendar dominated by 7-day acclimation + 7-day finish cure.

DRN-FAM-001 · Tony Koop · Maker Nexus · 2026-05-05

4 / 14

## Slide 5

Design Sheet Highlights

Drone-Flutes-Design.xlsx — single source of truth.

What it does
Six sheets, 284 formulas, all driven by one Master_Inputs sheet of named global variables. SolidWorks reads from the same Excel via a linked design table.
Edit one, change all
Drone offset is a single semitone variable. Flip from unison to fifth-below across all 4 flutes in one cell edit. Same for concert pitch (440 → 432) or bore size sweeps.
Empirical correction baked in
K2 piecewise lookup by bore_ID — five segments from −2.0% to +1.3% — applied automatically. Comes from Tony's 150+ NAF measurements.

Member | Key | f0 (Hz) | Bore | L_total
DRN-Am | Am | 440.00 | 0.750" | 21.97"
DRN-Fsm | F#m | 369.99 | 0.875" | 24.99"
DRN-Em | Em | 329.63 | 1.000" | 27.23"
DRN-Dm | Dm | 293.67 | 1.125" | 29.82"

All chamber-to-bore ratios sit in the 17–21 sweet spot.

DRN-FAM-001 · Tony Koop · Maker Nexus · 2026-05-05

5 / 14

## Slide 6

BOM & Sourcing

Materials, tooling, and where to buy.

$516

first-build total

$271 each subsequent build (tooling already on hand)

Group | Subtotal
Wood — walnut bodies + drone stock | $193
Wood — maple inlay (3 sheets) | (in $193)
Hardware + finish (Tru-Oil, glue, leather) | $78
CNC tooling — 4 bits + 8 drills (one-time) | $245
Files — generated in V-Carve | $0

IDC Woodcraft
CNC bits — solid carbide spirals

Suppliers

Hardwoods to Get
Walnut S4S body blanks + drone stock

Bell Forest Products
Hard maple thin stock for inlay

RFQ drafts ready in supplier-rfq.md — adapt contact info and send.

DRN-FAM-001 · Tony Koop · Maker Nexus · 2026-05-05

6 / 14

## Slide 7

Drawings · CAD · CNC

From parametric source to G-code.

Drawings (SVG)

SolidWorks

CNC G-code

- Per-key dimensioned drawing
drawings/{Am,Fsm,Em,Dm}.svg
- Family overview to scale
drawings/family-overview.svg
- Exploded assembly
drawings/assembly.svg
- Per-flute hole schedule callout
- Datum chain: FOOT → WINDOW → SOCKET

- Master sketch on Front plane
- Configurations: Am · F#m · Em · Dm
- Linked design table to Excel
- Global vars match Excel exactly
- K2 cascade in IIF equations
- DroneFlute_Master.SLDPRT
- DroneFlute_Bird.SLDPRT
- DroneFlute_DroneBlock.SLDPRT

- Generated in V-Carve from DXFs
- Bore profile (1/4 downcut)
- SAC pocket (1/4 downcut)
- Splitting edge (1/16 upcut climb)
- Faceting (1/2 downcut, V-block)
- Inlay pocket (1/16 upcut)
- Inlay plug (1/16 upcut, +0.001")
- Tone holes (drill press)

DRN-FAM-001 · Tony Koop · Maker Nexus · 2026-05-05

7 / 14

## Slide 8

Inlay Patterns

Broinwood-inspired CNC inlay across 8 facets per flute.

Band 1 (15% from foot)

Repeating chevron · Hard maple · 0.060" deep

32

inlay files

4 keys × 4 patterns × 2 formats (SVG + DXF)

96

pocket-and-plug ops to build the family

Band 2 (50%)

Repeating chevron · Hard maple · 0.060" deep

Band 3 (82%)

Diamond + corner dots · Hard maple · 0.060" deep

Feature panel (one facet)

7-star constellation + arrow · 0.080" deep · figured maple optional

DRN-FAM-001 · Tony Koop · Maker Nexus · 2026-05-05

8 / 14

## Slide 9

Visual BOM Brief

Image-forward resource view (renders after photoshoot).

HERO IMAGE PLACEHOLDER

All 4 finished flutes laid out from longest (Dm) to shortest (Am) with drone block sets fanned out in front.

Layout reference

- Header: title + quote date + estimated cost
- Hero image (4 flutes + drone blocks)
- Spreadsheet table from bom.csv
- Thumbnails (0.75") embedded per row
- 3 sub-assembly callouts (right margin)
- Render at 11×17 tabloid, 300 dpi

Status

- Hero photo: TBD (shoot after Phase 12)
- Sub-assembly renders: TBD (after Phase 9-10)
- Component thumbnails: supplier images OK as placeholders

DRN-FAM-001 · Tony Koop · Maker Nexus · 2026-05-05

9 / 14

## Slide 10

Assembly Summary

Twelve-phase shop run. Full text in assembly-manual.md.

Stock & Bore

Phase 1-4

Form & Finish (cuts)

Phase 5-8

Assembly & QA

Phase 9-12

1. Mill walnut S4S, acclimate 7 days
2. Bandsaw blank in half along long axis
3. CNC bore + SAC + splitting-edge halves
4. Glue, clamp 24 h, lathe round to body_OD

1. V-block jig — 8 facet passes on CNC
2. Drill 6 tone holes from foot datum
3. Plunge window + finish splitting edge
4. Inlay 24 ops × 4 flutes = 96 pocket/plug

1. Lathe-turn 12 drone blocks (3/flute)
2. Cut + laser-engrave 4 bird blocks
3. Tru-Oil finish 4-6 coats; cure 7 days
4. Tune to ±5 cents; record validation.csv

DRN-FAM-001 · Tony Koop · Maker Nexus · 2026-05-05

10 / 14

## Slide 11

Tuning & Validation

Predictions ship; measurements feed back.

±5

cents tolerance per note

44 measurements per family
(11 notes × 4 flutes)

How validation feeds back

Tune each finished flute, all notes + drones, with a chromatic tuner. Record cents error.

1

2

Write measurement to validation.csv for that flute / note.

3

Run scripts/record_measurement.py — updates per-family corrections database.

Most likely fail modes

- Hole 6 (octave) sharp
- Drone–melody chamber leak
- Splitting edge too thick (breathy)

4

If a sibling flute's prediction shifts by >2 cents, generator flags it.

5

Next family in the same lineage uses the updated K2 table automatically.

DRN-FAM-001 · Tony Koop · Maker Nexus · 2026-05-05

11 / 14

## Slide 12

Open Risks

Red-team failure-mode walk · risks.md

Hole 6 (octave) sharp

Test: Tune-step inspection; capture per-flute correction if >+5 cents on more than 2 of 4 flutes.

A-1

ACOUSTIC

SEV MED

Drone–melody chamber leak

Test: Pre-glue ridge-feel check + post-glue isolated melody puff test.

A-2

ACOUSTIC

SEV HIGH

Walnut splits along glue line

Test: Same-blank halves + matched MC; Type II glue + 6+ clamps; 40-50 % RH storage.

S-1

STRUCTURAL

SEV HIGH

Em/Dm hole reach for small hands

Test: 5th-percentile span check: H1↔H6 < 6" for the lower keys.

E-1

ERGONOMIC

SEV LOW

Walnut sapwood streaks

Test: Order with 'no visible sapwood' spec; reject deliveries >10 % sapwood by area.

Su-2

SUPPLY

SEV MED

Inlay flush-sand removes too much body

Test: Pre/post caliper at each band — diff must be < 0.005".

F-1

FIT/FINISH

SEV LOW

DRN-FAM-001 · Tony Koop · Maker Nexus · 2026-05-05

12 / 14

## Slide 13

Next Actions

What ships next.

1

Send the 3 RFQs (Hardwoods to Get, Bell Forest, IDC). Lock prices and lead time.

2

Acclimate walnut + maple in Tony's shop for 7 days.

3

Generate G-code in V-Carve from the SolidWorks DXFs after blanks arrive.

4

Build flute 1 (F#m, the canonical) end-to-end to validate the workflow.

5

Tune. Record measurements through record_measurement.py.

6

Photograph the 4-flute set after Phase 12 to replace the visual-BOM placeholder.

7

Publish site/ to GitHub Pages on the drone-flutes repo.

DRN-FAM-001 · Tony Koop · Maker Nexus · 2026-05-05

13 / 14

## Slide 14

Thank you

Drone Flute Family · DRN-FAM-001

Resources

GitHub repo · github.com/tonykoop/drone-flutes
Build-log site · site/index.html (in this packet)
Print packet · print-packet.pdf
Sister repos · flutes · fujara · transverse-flute · shakuhachi

Tony Koop · tonykoop@gmail.com · Maker Nexus, South Bay

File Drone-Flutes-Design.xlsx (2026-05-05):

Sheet: Index
Native American Drone Flute — Design Workbook
Inspired by Elemental Flutes (gallery) + Broinwood CNC inlay aesthetic. Drives SolidWorks master layout.
Author: Tony Koop | Tools: ShopBot CNC, lathe, Epilog laser, SolidWorks | Maker Nexus, South Bay
Sheet | Purpose | Edit?
Master_Inputs | Global variables — every other formula references these. Same names as SolidWorks globals. | Blue cells
Design_Table | Per-key dimensions (F#m, Em, Dm, Am). Bore length, wall, drone chamber, SAC, total length. | Inputs only
Hole_Schedule | Six-hole pentatonic minor scale layout per key — frequency, position from foot, diameter. | Diameters only
Wood_Library | Tonewood reference (E, ρ, Janka). Walnut + Maple are the chosen pair; alternates listed. | Reference
Inlay_Layout | Geometric band positions on the body and feature-panel sizing for each key. | Inputs only
Color key
Blue text on light blue = USER INPUT
Black text = formula (do not edit — overwriting destroys the parametric chain)

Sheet: Master_Inputs
Master Inputs — Global Variables
These are the ONLY hand-edited values in the workbook. Every other sheet derives from these.
Names match the global variables in the SolidWorks master layout (see SW reference doc).
ACOUSTIC CONSTANTS
Variable | Value | Unit | Notes
c_speed_of_sound | 13552 | in/s | Speed of sound at 68°F (20°C). Adjust if shop temp differs significantly.
T_shop_temp_F | 68 | °F | Shop reference temperature. c = 13190.6 * SQRT(1 + (T-32)/(1.8*273.15))
A4_reference | 440 | Hz | Concert pitch reference. A4 = 440 Hz. Change to 432 for alt tuning.
end_correction_k | 0.6 | - | Open-end correction multiplier. f_eff_extra_length = k × radius.
SAC + BIRD GEOMETRY
SAC_length | 5.5 | in | Slow Air Chamber length. Standard NAF range 5–6". Affects breath response.
SAC_wall_thickness | 0.25 | in | Wall between SAC and main bore (the "splitting edge" wall).
flue_gap | 0.04 | in | Window/flue gap. Critical for tone — typical 0.030–0.050".
bird_length | 2 | in | Length of the totem/bird block sitting on top of the SAC.
bird_height | 0.75 | in | Height of bird block above the body OD.
window_length | 0.625 | in | TSH (true sound hole) window length under the bird.
window_width | 0.625 | in | Window width.
DRONE BLOCK (TUNABLE/SWAPPABLE)
drone_offset_semitones | 0 | st | Drone tuning offset from melody fundamental. 0=unison, -7=5th below, -12=octave below.
drone_block_length | 3.5 | in | Length of swappable drone foot block. Three blocks made: unison/-7/-12.
drone_block_OD_factor | 1 | - | Drone block OD multiplier vs body OD. 1.0 = same. >1 = stepped foot.
drone_tenon_length | 0.75 | in | Length of tenon engagement into main body (drilled socket).
drone_tenon_clearance | 0.005 | in | Slip-fit clearance: tenon OD = socket ID − this. 0.003–0.008".
FACETED EXTERIOR (HYBRID CONSTRUCTION)
n_facets | 8 | count | Number of flat sides around the body. 8 = octagon (selected).
facet_chord_factor | 0.4142 | - | TAN(PI/n_facets). For octagon = 0.4142. Side length = OD x this.
facet_inlay_inset | 0.1 | in | Inset from facet edge for inlay banding (per side).
OD_to_flat_factor | 1 | - | After faceting, OD becomes flat-to-flat. Round blank turned to ID + 2*wall + facet allowance.
facet_allowance | 0.05 | in | Extra material left for faceting passes after lathe rounding.
K2 EMPIRICAL CORRECTIONS BY BORE (Tony's data)
Bore_lower | Bore_upper | K2_correction | Notes
0 | 0.749 | -2.000% | Small bore — model overestimates length
0.75 | 0.874 | -0.700% | Std small NAF bore
0.875 | 0.999 | 0.400% | Crossover / neutral
1 | 1.124 | 0.700% | Mid
1.125 | 9.999 | 1.300% | Large bore — model underestimates length

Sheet: Design_Table
Drone Flute Design Table
Per-key dimensions. Blue cells are inputs; everything else is a formula.
Drone offset is shared from Master_Inputs.drone_offset_semitones (default 0 = unison).
Parameter | Unit | Am | F#m | Em | Dm
PITCH & FREQUENCY
MIDI_note | midi# | 69 | 66 | 64 | 62
fundamental_freq | Hz | 440.00 | 369.99 | 329.63 | 293.66
drone_freq | Hz | 440.00 | 369.99 | 329.63 | 293.66
BORE & BODY DIMENSIONS
bore_ID | in | 0.750 | 0.875 | 1.000 | 1.125
wall_thickness | in | 0.250 | 0.250 | 0.250 | 0.250
body_OD_round | in | 1.300 | 1.425 | 1.550 | 1.675
body_OD_flat_to_flat | in | 1.200 | 1.325 | 1.450 | 1.575
facet_side_length | in | 0.497 | 0.549 | 0.601 | 0.652
K2_correction | % | -0.70% | 0.40% | 0.70% | 1.30%
ACOUSTIC LENGTHS (open-open pipe)
L_acoustic_raw | in | 15.400 | 18.314 | 20.557 | 23.074
L_acoustic_corrected | in | 15.292 | 18.387 | 20.700 | 23.374
end_corr_each_end | in | 0.225 | 0.263 | 0.300 | 0.338
L_bore_physical | in | 14.842 | 17.862 | 20.100 | 22.699
chamber_to_bore_ratio | - | 20.4 | 21.0 | 20.7 | 20.8
DRONE CHAMBER (separate parallel bore)
drone_bore_ID | in | 0.625 | 0.750 | 0.875 | 1.000
drone_K2 | % | -2.00% | -0.70% | 0.40% | 0.70%
drone_L_acoustic | in | 15.092 | 18.186 | 20.639 | 23.235
drone_end_corr | in | 0.188 | 0.225 | 0.263 | 0.300
drone_L_physical | in | 14.717 | 17.736 | 20.114 | 22.635
drone_block_total_L | in | 4.250 | 4.250 | 4.250 | 4.250
TOTAL FLUTE LENGTH
L_SAC | in | 5.500 | 5.500 | 5.500 | 5.500
L_total_flute | in | 21.967 | 24.987 | 27.225 | 29.824
L_total_with_drone | in | 25.467 | 28.487 | 30.725 | 33.324
STOCK / BLANK SIZING (rough cut)
blank_length | in | 23.967 | 26.987 | 29.225 | 31.824
blank_thickness | in | 1.550 | 1.675 | 1.800 | 1.925
blank_width | in | 1.550 | 1.675 | 1.800 | 1.925
split_blank_thickness | in | 0.775 | 0.838 | 0.900 | 0.963

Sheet: Hole_Schedule
Hole Schedule — Pentatonic Minor (NAF Mode 1/4)
Hole positions measured from FOOT (open end). Hole 1 is closest to the foot, plays m3.
Formula: pos_from_foot = L_acoustic_corrected × (1 − fundamental_freq/hole_freq). Window reference = L_acoustic − pos_from_foot.
Hole | Am |  |  | F#m |  |  | Em |  |  | Dm
Semitone offset → | Δst | Hz | pos from foot (in) | Δst | Hz | pos from foot (in) | Δst | Hz | pos from foot (in) | Δst | Hz | pos from foot (in)
Hole 1 (m3) | 3 | 523.25 | 2.433 | 3 | 440.00 | 2.925 | 3 | 392.00 | 3.294 | 3 | 349.23 | 3.719
Hole 2 (P4) | 5 | 587.33 | 3.836 | 5 | 493.88 | 4.612 | 5 | 440.00 | 5.193 | 5 | 392.00 | 5.863
Hole 3 (P5) | 7 | 659.26 | 5.086 | 7 | 554.37 | 6.115 | 7 | 493.88 | 6.885 | 7 | 440.00 | 7.774
Hole 4 (m6) | 8 | 698.46 | 5.659 | 8 | 587.33 | 6.804 | 8 | 523.25 | 7.660 | 8 | 466.16 | 8.649
Hole 5 (m7) | 10 | 783.99 | 6.710 | 10 | 659.26 | 8.068 | 10 | 587.33 | 9.083 | 10 | 523.25 | 10.256
Hole 6 (oct) | 12 | 880.00 | 7.646 | 12 | 739.99 | 9.194 | 12 | 659.26 | 10.350 | 12 | 587.33 | 11.687
HOLE DIAMETERS
Hole | Am — Ø (in) |  |  | F#m — Ø (in) |  |  | Em — Ø (in) |  |  | Dm — Ø (in)
Hole 1 (m3) | 0.250 | 6.4 mm | ok | 0.281 | 7.1 mm | ok | 0.312 | 7.9 mm | ok | 0.344 | 8.7 mm | ok
Hole 2 (P4) | 0.281 | 7.1 mm | ok | 0.312 | 7.9 mm | ok | 0.344 | 8.7 mm | ok | 0.375 | 9.5 mm | ok
Hole 3 (P5) | 0.281 | 7.1 mm | ok | 0.312 | 7.9 mm | ok | 0.344 | 8.7 mm | ok | 0.375 | 9.5 mm | ok
Hole 4 (m6) | 0.281 | 7.1 mm | ok | 0.312 | 7.9 mm | ok | 0.344 | 8.7 mm | ok | 0.375 | 9.5 mm | ok
Hole 5 (m7) | 0.281 | 7.1 mm | ok | 0.312 | 7.9 mm | ok | 0.344 | 8.7 mm | ok | 0.375 | 9.5 mm | ok
Hole 6 (oct) | 0.281 | 7.1 mm | ok | 0.312 | 7.9 mm | ok | 0.344 | 8.7 mm | ok | 0.375 | 9.5 mm | ok
HOLE-TO-HOLE SPACING (check ≥ 0.40 in for finger comfort)
Between | Am — Δ (in) |  |  | F#m — Δ (in) |  |  | Em — Δ (in) |  |  | Dm — Δ (in)
H1↔H2 | 1.403 | ok |  | 1.687 | ok |  | 1.899 | ok |  | 2.144 | ok
H2↔H3 | 1.250 | ok |  | 1.503 | ok |  | 1.692 | ok |  | 1.910 | ok
H3↔H4 | 0.573 | ok |  | 0.689 | ok |  | 0.775 | ok |  | 0.876 | ok
H4↔H5 | 1.051 | ok |  | 1.264 | ok |  | 1.423 | ok |  | 1.606 | ok
H5↔H6 | 0.936 | ok |  | 1.126 | ok |  | 1.268 | ok |  | 1.431 | ok
CNC REFERENCE: POSITION FROM WINDOW (splitting edge)
Hole | Am — pos from window (in) |  |  | F#m — pos from window (in) |  |  | Em — pos from window (in) |  |  | Dm — pos from window (in)
Hole 1 (m3) | 12.859 |  |  | 15.462 |  |  | 17.407 |  |  | 19.655
Hole 2 (P4) | 11.456 |  |  | 13.775 |  |  | 15.508 |  |  | 17.511
Hole 3 (P5) | 10.206 |  |  | 12.272 |  |  | 13.816 |  |  | 15.600
Hole 4 (m6) | 9.633 |  |  | 11.583 |  |  | 13.040 |  |  | 14.725
Hole 5 (m7) | 8.582 |  |  | 10.319 |  |  | 11.618 |  |  | 13.118
Hole 6 (oct) | 7.646 |  |  | 9.194 |  |  | 10.350 |  |  | 11.687

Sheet: Wood_Library
Tonewood Reference
Walnut + Maple is the chosen pairing. Alternates listed for reference.
Species | Role | E (GPa) | ρ (kg/m³) | Janka (lbf) | Color | Workability | Notes
Black Walnut | Body (chosen) | 11.6 | 610 | 1010 | Dark chocolate brown | Excellent | Stable, classic NAF body. Glues well after sealing pores.
Hard Maple | Inlay (chosen) | 12.6 | 705 | 1450 | Pale cream | Good | High contrast against walnut. Curly maple for premium versions.
Cherry | Body alt | 10.3 | 560 | 950 | Warm reddish brown | Excellent | Darkens beautifully with UV. Good acoustic match.
Padauk | Inlay accent alt | 11 | 745 | 1725 | Bright orange-red | Good | Stunning color but oxidizes to brown over years.
Wenge | Inlay alt | 15.8 | 870 | 1630 | Near-black with stripe | Difficult | Splintery — wear gloves. Striking with maple.
Yellowheart | Inlay accent | 10 | 800 | 1820 | Bright yellow | Good | Holds color well. Use for small accents (stars, dots).
Western Red Cedar | Body (light/airy) | 7.7 | 370 | 350 | Pinkish brown | Excellent | Ultra-light bodies. Lower density = brighter tone.
Mahogany | Body alt | 10.1 | 590 | 900 | Reddish brown | Excellent | Warm tone, stable, easy to CNC.

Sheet: Inlay_Layout
Inlay Layout — Geometric Bands + Feature Panel
Broinwood-inspired geometric bands wrapping around all 8 facets, plus one feature panel near the bird block.
Parameter | Unit | Am | F#m | Em | Dm
FACET LAYOUT
n_facets | - | 8 | 8 | 8 | 8
facet_side_length | in | 0.497 | 0.549 | 0.601 | 0.652
inlay_band_width | in | 0.297 | 0.349 | 0.401 | 0.452
GEOMETRIC BAND POSITIONS (from foot)
band1_pct
band2_pct
band3_pct
band1_pos_from_foot | in | 0.000 | 0.000 | 0.000 | 0.000
band2_pos_from_foot | in | 0.000 | 0.000 | 0.000 | 0.000
band3_pos_from_foot | in | 0.000 | 0.000 | 0.000 | 0.000
GEOMETRIC BAND DIMENSIONS
band_height
band_inlay_depth
band_pattern
chevron_pitch
FEATURE PANEL (one facet, between band2 and band3)
feature_facet_index
feature_panel_height | in | 7.030 | 7.996 | 8.712 | 9.544
feature_panel_pos_from_foot | in | 12.082 | 13.743 | 14.974 | 16.403
feature_pattern
feature_inlay_depth
CNC POCKET STRATEGY
pocket_bit | - | 1/16" upcut | 1/16" upcut | 1/16" upcut | 1/16" upcut
plug_bit | - | 1/16" upcut | 1/16" upcut | 1/16" upcut | 1/16" upcut
plug_oversize
pocket_clearance

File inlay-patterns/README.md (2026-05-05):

# Inlay Patterns — Drone Flute Set

This folder contains CNC inlay artwork for all four drone flutes (Am, F#m, Em, Dm).

Each subfolder is sized to that key's facet dimensions (a smaller flute = narrower facets = smaller artwork). All files anchor at origin (0,0) bottom-left for direct import into V-Carve.

## Per-key dimension summary

| Key | Band width × height | Feature panel width × height |
|-----|---|---|
| Am | 0.297 × 0.500 in | 0.297 × 7.029 in |
| F#m | 0.349 × 0.500 in | 0.349 × 7.996 in |
| Em | 0.401 × 0.500 in | 0.401 × 8.712 in |
| Dm | 0.452 × 0.500 in | 0.452 × 9.544 in |

## File pairs

For each key:
- `band1_chevron` / `band2_chevron` — repeating chevron pattern (lower + center bands)
- `band3_diamond` — diamond + corner dot pattern (upper band, just below the bird block)
- `feature_constellation` — stylized 7-star constellation with directional arrow (single feature panel per flute)

Each pattern has both `.svg` (preview) and `.dxf` (CAM import) versions.

## Recommended toolpath strategy

1. **Pocket pass** — 1/16" upcut spiral, 18000 rpm, 60 ipm. Depth: 0.060" for bands, 0.080" for feature panels.
2. **Plug pass** — same bit on separate maple stock fixture. Outside offset +0.001" to create interference fit.
3. **Glue & flush sand** — Starbond thin CA, then 220-grit flat block.

See `Drone-Flutes-BOM-Build-Method.docx` Phase 8 for the full inlay procedure.

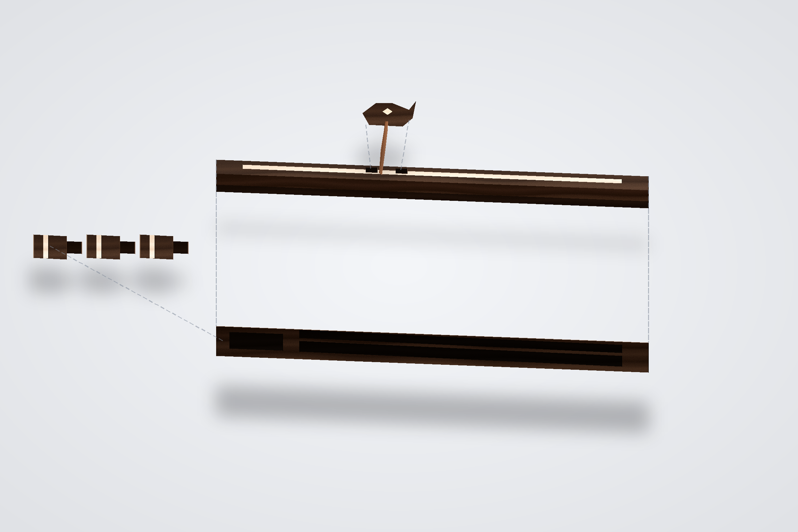
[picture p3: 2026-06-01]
images/exploded-diagram.png

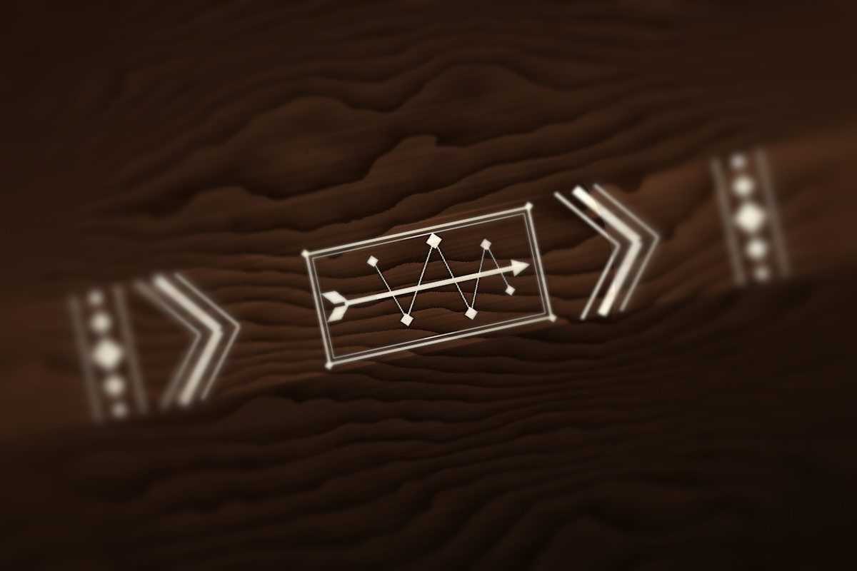
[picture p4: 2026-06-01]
images/macro/facet-inlay.png

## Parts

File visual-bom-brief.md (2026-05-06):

# Visual BOM Brief — Drone Flute Family

Reference layout: `C:\Users\Tony\Documents\GitHub\ashiko-drum-workshop\images\figure-bom-v2.png`.

## Header block

- **Title:** "Drone Flute Family — Build Resources"
- **Sub:** "DRN-FAM-001 · Walnut + Maple · ShopBot CNC + lathe + Epilog laser · Maker Nexus"
- **Quote date:** 2026-05-05
- **Estimated cost:** $516 (materials + tooling)
- **Build window:** 8 weeks total

## Hero image

Single hero showing all four finished flutes laid out from longest (Dm, ~30 in) to shortest (Am, ~22 in) on a neutral linen drop, with the swappable drone blocks fanned out in front of each flute. Bird blocks on top facets, leather laces visible.

If hero photography isn't done yet, use `images/hero-placeholder.svg` (a labelled scale outline of the four flutes side-by-side) and mark it as a placeholder.

## Spreadsheet area

Reproduce `bom.csv` as a table with these columns and a thumbnail per row:

| # | Part | Image | Qty | Spec | Material | Supplier | Unit $ | Line $ |
|---|---|---|-----|---|---|---|---|---|

- Group rows by `category` (wood / hardware / consumables / tooling / files).
- Strong column headers, alternating row fills (#F2F2F2 / white).
- Thumbnails are 0.75 × 0.75 in. Walnut blank = stock photo; inlay maple = stock photo; bits = supplier images.
- Right-align numbers.

## Sub-assembly callouts

Three subsystem images on the right margin:
1. **Body cross-section** — exploded view showing left half / right half / drone block. Overlay the bore profile on the cross-section.
2. **Bird block** — single 3D render with leather lace.
3. **Drone block set** — three blocks (U / 5 / 8) in a row with engraved tags visible.

## Footnotes

- "All wood specs assume 6–8 % MC. Acclimate 7 days before machining."
- "Pricing dated 2026-05-05; verify with `sourcing.csv` before purchasing."
- "Tool inventory assumes Maker Nexus access; if building elsewhere, add ShopBot/lathe/Epilog rental costs."

## Image sourcing status

| Image | Status | Path |
|---|---|---|
| hero-finished-set.jpg | TBD | needs photoshoot after Phase 12 |
| body-cross-section.svg | partial | covered by `drawings/Am.svg` etc., needs section overlay |
| bird-block.png | TBD | render after Phase 10 |
| drone-block-set.png | TBD | render after Phase 9 |
| walnut-blank.jpg | placeholder | use Hardwoods to Get product photo |
| maple-blank.jpg | placeholder | use Bell Forest product photo |
| 1-16-upcut.jpg | placeholder | use IDC Woodcraft product photo |

## Output

Render the visual BOM as `images/visual-bom.png` at 11×17 (tabloid) at 300 dpi. Inline a copy in `print-packet.pdf` and `site/index.html`.

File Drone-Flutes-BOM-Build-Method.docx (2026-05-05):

Native American Drone Flute

Bill of Materials & Build Method

Set of 4 (F#m | Em | Dm | Am) - Walnut + Maple inlay - ShopBot CNC + lathe + Epilog laser

# 1. Project Summary

This document covers the materials, tools, and step-by-step build method for a set of four Native American drone flutes (Am, F#m, Em, Dm) inspired by the elementalflutes.com gallery, with broinwood-style geometric inlay across all eight facets and a feature panel on one facet of each flute. Construction is hybrid: split-body CNC for the interior chambers, lathe rounding, then CNC facet pass for the exterior. Each flute ships with a tunable drone block set (3 swappable blocks: unison, fifth, octave).

Estimated build time: 60-80 shop hours across 4-6 weeks (acclimation and finish cure dominate calendar time).

Estimated material cost: $516. Tools and bits are largely already on hand at Maker Nexus and Tony's home shop.

# 2. Bill of Materials

Quantities are for the complete set of 4 flutes plus a 25 percent waste/test factor. Pricing is approximate as of mid-2026.

## 2.1 Wood Stock

# | Item | Qty | Spec | Source | Cost

1.1 | Body blank | 4 | Black walnut, S4S, 1.5x1.5x32 in | Hardwoods to Get / local | $22 ea = $88
1.2 | Body blank (Em, Dm) | 2 | Black walnut, S4S, 1.75x1.75x36 in | Hardwoods to Get / local | $30 ea = $60 (replaces 1.1 for the 2 lower keys)
1.3 | Inlay stock - bands | 2 | Hard maple, 1/16x2x24 in | Inventables / Bell Forest | $8 ea = $16
1.4 | Inlay stock - feature panel | 1 | Hard maple, 1/8x4x12 in (figured if available) | Bell Forest | $14
1.5 | Bird block stock | 1 | Black walnut, 1x1x10 in (cut to 4 blocks) | Scrap or 1.1 offcut | $0 (offcut)
1.6 | Drone block stock | 1 | Black walnut, 1.75x1.75x18 in (cut to 12 blocks: 3 per flute) | Hardwoods to Get | $15

Subtotal: $193

## 2.2 Hardware & Finish

# | Item | Qty | Spec | Source | Cost

2.1 | Leather lacing for bird tie | 4 ft | Natural latigo, 3/16 width | Tandy Leather | $6
2.2 | Sealer/finish - Tru-Oil | 1 bottle | 3 oz | Brownells / Amazon | $10
2.3 | Carnauba wax | 1 tin | Howards Feed-N-Wax 16 oz | Hardware store | $10
2.4 | Painter tape, 1 in blue | 1 roll | 3M ScotchBlue | Hardware store | $6
2.5 | Sandpaper assortment | 1 set | 120, 180, 220, 320, 400, 600 grit | Hardware store | $15
2.6 | Wood glue | 1 bottle | Titebond II Premium 16 oz | Hardware store | $8
2.7 | CA glue (thin) | 1 bottle | Starbond EM-02 Super Fast Thin 2 oz | Starbond | $10
2.8 | CA accelerator | 1 bottle | Starbond NCF Quick Set Accelerator | Starbond | $8
2.9 | Foam tipped applicators | 20 ct | For Tru-Oil application | Amazon | $5

Subtotal: $78

## 2.3 CNC Tooling & Drill Bits

# | Item | Qty | Spec | Source | Cost

3.1 | CNC tooling - 1/16 upcut spiral | 1 | Carbide, 1/8 shank, 1/2 LOC | IDC Woodcraft | $22
3.2 | CNC tooling - 1/4 downcut spiral | 1 | Carbide, 1/4 shank, 1 LOC | IDC Woodcraft | $32
3.3 | CNC tooling - 1/2 downcut spiral | 1 | Carbide, 1/2 shank, 1.25 LOC | IDC Woodcraft | $45
3.4 | CNC tooling - 3/4 ball end | 1 | Carbide, 1/2 shank, 1.5 LOC | IDC Woodcraft | $58
3.5 | Lathe tools | use existing | Roughing gouge, skew, parting tool | Tony has these | -
3.6 | Drill bits for tone holes | 4 | 1/4, 9/32, 5/16, 11/32 brad-point | Lee Valley | $22
3.7 | Reamer for SAC channel | 1 | 7/8 long-spur saw bit | Lee Valley | $18
3.8 | Forstner bits (drone socket) | 4 | 5/8, 3/4, 7/8, 1 in | Lee Valley | $48

Subtotal: $245 (one-time tooling)

## 2.4 CAD/CAM Files

# | Item | Qty | Spec | Source | Cost

4.1 | CNC G-code - bore profile pass | 4 files | One per key. Generated from SolidWorks via Vectric V-Carve. | Tony | -
4.2 | CNC G-code - facet pass | 4 files | One per key. Octagon facet cuts. | Tony | -
4.3 | CNC G-code - inlay pocket | 12 files | 3 bands x 4 keys. | Tony | -
4.4 | CNC G-code - inlay plug | 12 files | Mating plugs cut from 1/16 maple. | Tony | -
4.5 | CNC G-code - feature panel | 4 files | Pocket and plug pair per key. | Tony | -
4.6 | CNC G-code - finger holes | 4 files | Six holes per flute, drilled or routed. | Tony | -
4.7 | CNC G-code - drone block tenon | 4 files | Lathe-turned alternative possible. | Tony | -

Files only - no dollar cost

## 2.5 Total

Total estimated material + tooling cost for the set: $516 + tooling already on hand

# 3. Tools & Equipment Inventory

Maker Nexus equipment (in the South Bay):

- ShopBot CNC router (4x8 bed)
- Wood lathe (12 in swing minimum, 36 in between centers)
- Epilog laser cutter (60W or 75W)
- Drill press
- Bandsaw, jointer, planer, table saw, drum sander

Tony's home shop:

- SolidWorks (parametric CAD)
- Vectric V-Carve (CAM for ShopBot)
- Hand tools (chisels, files, scrapers, calipers)
- Chromatic tuner (Korg or smartphone app)

# 4. CNC Toolpath Quick Reference

Recommended speeds and feeds. Tony will tune in the shop based on bit wear and spoilboard condition.

Phase | Operation | Bit | Spindle (rpm) | Feed (ipm) | Depth/Pass | Notes
2 | Bore profile | 1/4 downcut | 18000 | 80 | 0.250 | 2 passes max
2 | SAC pocket | 1/4 downcut | 18000 | 80 | 0.250 | 2 passes
2 | Splitting edge wall | 1/16 upcut | 20000 | 40 | 0.060 | Climb cut, single pass
5 | Facet flattening | 1/2 downcut | 16000 | 120 | 0.080 | 8 facets x 1 pass each
8 | Inlay band pocket | 1/16 upcut | 18000 | 60 | 0.060 | Plunge 20 ipm
8 | Inlay plug profile | 1/16 upcut | 18000 | 60 | 0.030 | Plug stock = 1/16 maple
8 | Feature panel pocket | 1/16 upcut | 18000 | 60 | 0.080 | Single pass
6 | Tone hole drill | brad-point | drill press 1500 | manual | thru | Backer dowel inside bore

Speeds and feeds are starting points. Verify on a scrap blank before committing.

# 5. Build Method

The build is organized into 13 phases, executed in order. Each phase has explicit steps with the relevant Excel/SolidWorks references baked in.

Phase 0: Design & CAD Prep

1. Confirm A=440 reference; if alternate tuning desired, edit Master_Inputs!B9 in Excel and re-export.
2. Open Drone-Flutes-Design.xlsx. Verify each key's row in Design_Table looks correct (length, bore, drone bore).
3. Open DroneFlute_Master.SLDPRT in SolidWorks. Update from external reference (Excel) if prompted.
4. Switch through configurations Am/F#m/Em/Dm to confirm geometry rebuilds without errors.
5. Save As DXF: each facet face, each inlay sketch, the window cutout, and the hole-center sketch. Save to /Drone-Flutes/inlay-patterns/{key}/ folders.
6. Generate G-code in V-Carve. Use the bit list in BOM section 3 and the toolpath table below.
7. Sanity-check G-code in V-Carve preview before sending to ShopBot.

Phase 1: Stock Prep

8. Mill all walnut blanks to S4S (squared four sides). Final blank dimensions per key from Design_Table!blank_thickness and blank_length.
9. Joint one face flat and joint one edge square. Plane to thickness. Rip to width. Cut to length +1.5 in for end-grain trim.
10. Inspect grain orientation: long grain MUST run parallel to the bore axis. Reject any blank with end-grain runout exceeding 1:12.
11. Mark center reference line on every blank with a marking gauge or laser pointer along the long axis.
12. Drill three datum holes (3/16) on each blank for CNC alignment pins. Locations: 1 in from each end and one in the middle.
13. Acclimate blanks in Tony's shop for at least 7 days before the next phase.

Phase 2: Split-Body CNC (Bore + SAC)

14. Resaw each blank exactly down the center using the bandsaw. Save the saw kerf - clean both halves with a hand plane to glue-ready surfaces.
15. Mark each pair (left half / right half) with the same key letter so they don't get mixed.
16. Set up CNC with 1/4 downcut spiral. Load the bore-profile G-code for the active key.
17. Mount one half on the spoilboard with vacuum + datum pins. Run the bore-profile pass: 1/4 round-bottom channel = bore_ID/2 deep. Two passes recommended.
18. Run the SAC pocket: same depth, but with the SAC_length and SAC_wall geometry from the Excel sheet baked into the G-code.
19. Run the window/splitting-edge profile cut. Use 1/16 upcut for the splitting edge to leave a clean knife-thin wall.
20. Flip the second half onto the same fixture (alignment pins do their job here). Run the same G-code mirrored.
21. Repeat for all 4 keys (8 halves total).

Phase 3: Glue-Up

22. Dry-fit each pair. Ensure the bore aligns cleanly when the halves meet. If not, sand mating faces lightly on a granite plate.
23. Apply Titebond II to both mating faces. Use a thin, even coat.
24. Clamp with at least 6 clamps along the length, alternating top and bottom. Place wax paper between clamps and the body to keep glue squeeze-out from sticking.
25. Use the 3/16 dowels in the datum holes during glue-up to keep alignment perfect.
26. Wait 24 hours minimum before unclamping.
27. Inspect the glue line. If any visible gap, soak that area with thin CA + accelerator and re-clamp briefly.

Phase 4: Lathe Rounding

28. Mount each glued blank between centers on the lathe. Drive center on the foot end, live center on the SAC end.
29. Rough-turn to round at slow RPM (about 800). Use a 3/4 roughing gouge.
30. Final-turn to body_OD_round (Excel Design_Table). Leave 0.05 in extra (the facet_allowance) - this is removed by faceting.
31. Sand on the lathe through 220 grit while the body is true and concentric.
32. Mark a reference line along the entire length with a pencil while the lathe spins slowly. This is the seam datum for the next phase.

Phase 5: CNC Faceting

33. Build a V-block jig on the CNC bed: two pieces of MDF cut at 22.5 degrees each, plus end-stops to hold the body in axial position.
34. For octagon (8 facets), each pass orients the body so one facet is parallel to the spoilboard.
35. Load the 1/2 downcut spiral for facet flattening.
36. Run pass 1 to remove facet_allowance + a tiny bit more (0.005 in safety) to make the top facet dead flat.
37. Rotate the body 45 degrees in the V-block. Index using a pin or notch on the foot end.
38. Run pass 2. Repeat for all 8 facets.
39. Verify with calipers: body_OD_flat should match the Excel value within 0.010 in.

Phase 6: Tone Hole Drilling

40. Mount the body in a horizontal jig with the top facet (where holes will be drilled) facing up.
41. Set up a Forstner-style brad-point bit in the drill press. Use the diameter listed for each hole position (Hole_Schedule input cell).
42. Mark hole centers using positions from the Hole_Schedule sheet, measured from the FOOT.
43. Drill each hole carefully. Use a backer board inside the bore to prevent blowout (a piece of dowel slid into the bore).
44. After drilling, sand each hole interior with 320-grit rolled sandpaper to remove fuzz.
45. Tuning step: blow each hole open and use a chromatic tuner. Adjust by enlarging slightly with a chainsaw file or tapered reamer.
46. Once tuned, ease the inside top edge of each hole at a 30-degree angle - this is the undercut and gives the flute its character.

Phase 7: Window & Splitting Edge

47. Position the window cutout above the SAC-to-bore wall, on the top facet.
48. Use a 1/16 upcut to plunge a starting hole at the splitting-edge location.
49. Cut the window perimeter using the window_length x window_width sketch from SolidWorks.
50. Carefully shape the splitting edge with a small chisel and 320-grit sandpaper. The edge should be knife-sharp.
51. Test by gently puffing into the SAC end - you should hear a clean tone. If breathy, file the splitting edge sharper. If too thin, glue a small shim of veneer.

Phase 8: CNC Inlay (Pocket + Plug)

52. Reorient the body so each facet can be CNC-pocketed. Use the V-block jig from Phase 5.
53. Load the 1/16 upcut spiral. Set spindle to 18000 rpm, feed to 60 ipm, plunge to 20 ipm.
54. Run pocket G-code for band1, band2, band3 on each facet of the body. Depth = 0.060 in.
55. Switch to the maple inlay stock on a separate fixture. Run the matching plug G-code with 0.002 in oversize.
56. Test fit. If the plug binds, sand its underside lightly. If it falls in, the pocket was cut wide - use thicker CA to compensate.
57. Apply thin CA glue, press the plug into the pocket. Wait 20 seconds for cure.
58. Repeat for the feature panel (one chosen facet, between band 2 and band 3): pocket + plug, depth 0.080 in.
59. After all inlay is in place, surface-sand the body flat using a flat block and 220 grit. The plugs should sit flush.

Phase 9: Drone Block Set

60. Cut three drone block blanks per flute (12 total): unison, fifth, octave configurations.
61. Mount each blank on the lathe between centers. Turn the OD to body_OD_round (matching the body). Add the tenon at one end - diameter = bore_ID - drone_tenon_clearance, length = drone_tenon_len.
62. Drill the drone bore axially (use a long drill bit chucked in the tailstock). Depth and ID per Excel Design_Table drone_L_physical and drone_bore_ID for the matching key + drone offset.
63. For the unison block: drone bore matches melody fundamental - bore is the longest of the three.
64. For the fifth block: drone is 7 semitones below fundamental - bore is shorter.
65. For the octave block: drone is 12 semitones below fundamental - bore is shortest.
66. Sand each drone block to 320 grit. Apply finish (Phase 11) before final fit-test.
67. Engrave a small mark on the foot of each drone block with the laser cutter: U for unison, 5 for fifth, 8 for octave.

Phase 10: Bird Block

68. Cut bird block blanks from the offcut walnut: 2 in long, 0.75 in tall, body_OD_flat wide.
69. Use the laser cutter to engrave the totem pattern (eagle, wolf, bear, or geometric per flute personality).
70. Cut a flat shoulder on the bottom of each bird block to match the top facet of the body. The shoulder must align over the window.
71. Test position the bird block over the window. The flue gap is set by the bottom-edge profile of the bird - typical 0.030-0.050 in.
72. If gap is too small, sand the bottom of the bird. If too large, glue a thin shim of veneer to the bottom.

Phase 11: Finish

73. Final sand the entire body, drone blocks, and bird blocks: 220, 320, 400, 600 grit.
74. Wipe down with a tack cloth.
75. Apply Tru-Oil with a foam applicator. Thin first coat. Let dry 4-6 hours.
76. Sand with 600 grit between coats.
77. Apply 4-6 coats total. Final coat should be glassy.
78. Wait 7 days for full cure.
79. Buff with carnauba wax on a soft cloth. The flute should feel like silk.
80. Reapply wax every few months for long-term care.

Phase 12: Final Tuning & QA

81. Tie the bird block to the body with the leather lacing.
82. Insert the unison drone block first.
83. Play each note of the pentatonic minor scale. Use a chromatic tuner. Compare to Hole_Schedule!Hz columns.
84. If a note is sharp, deepen the hole (file out the wall slightly). If flat, partially fill the hole edge with thin CA.
85. Swap to the fifth drone block, then octave. Confirm each plays its expected drone pitch.
86. Record a video of all four flutes being played in sequence. Archive to /Drone-Flutes/qa/ folder.
87. Photograph each finished flute against a neutral background for the gallery.

# 6. Common Pitfalls & Mitigations

- Bore mismatch at glue-up: caused by datum pin slop. Mitigation: use 3/16 DOWELS not metal pins, slightly oversize so the pins crush-fit.
- Faceting tearout on grain reversal: feed direction matters. Mitigation: always cut walnut with the grain on the FACET pass; slow feed if you hear chatter.
- Window splitting edge too thin (collapses): caused by 1/16 upcut over-engaging. Mitigation: leave 0.005 in skin, finish with chisel.
- Inlay plug too loose: pocket cut wide due to bit deflection. Mitigation: do a test pocket on scrap first; adjust offset.
- Drone block too tight in socket: humidity. Mitigation: turn drone tenons in winter when wood is dry. Sand to fit if needed.
- Tuning sharp on hole 6 (octave): caused by hole too close to window. Mitigation: file the foot-side edge of the hole to effectively shift the hole away from the window.

# 7. Schedule

Suggested project timeline (calendar days). Many phases overlap; this is the critical path.

Week | Phase(s) | Key Outputs
Week 1 | Phase 0 (CAD), Phase 1 (stock acclimation) | G-code generated; blanks acclimating
Week 2 | Phase 2-3 (split-body CNC + glue-up) | Bore-profile bodies glued; 24h cure
Week 3 | Phase 4-7 (lathe, facets, holes, window) | All 4 bodies basically playable
Week 4 | Phase 8 (inlay) | Inlay complete on all bodies
Week 5 | Phase 9-10 (drone blocks + birds) | Block sets and birds finished
Week 6 | Phase 11 (finish) | Tru-Oil applied; cure time begins
Week 7 | Cure (no shop work) | Wait for finish to cure
Week 8 | Phase 12 (tuning + QA) | Photos, recordings, final inspection

# 8. Sign-off

This BOM and build method document is the master shop reference. The Excel design workbook (Drone-Flutes-Design.xlsx) is the source of truth for all numerical dimensions. The SolidWorks reference doc (Drone-Flutes-SolidWorks-MasterLayout.docx) is the master CAD setup guide.

Together these three documents fully specify the build.

Tony Koop | Maker Nexus | Page

Drone Flute - BOM & Build Method

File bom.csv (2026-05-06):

part_no | category | part_name | qty | units | spec | material | supplier | unit_cost_usd | line_total_usd | make_buy | drawing_ref | notes
1.1 | wood | Body blank, Am+F#m | 2 | each | 1.5×1.5×26 in S4S | Black walnut | Hardwoods to Get | 22 | 44 | buy | drawings/Am.svg, drawings/Fsm.svg | One blank per flute (Am, F#m).
1.2 | wood | Body blank, Em+Dm | 2 | each | 1.75×1.75×32 in S4S | Black walnut | Hardwoods to Get | 30 | 60 | buy | drawings/Em.svg, drawings/Dm.svg | Larger cross-section for the lower keys.
1.3 | wood | Inlay band stock | 2 | sheet | 1/16 × 2 × 24 in | Hard maple | Bell Forest | 8 | 16 | buy | inlay-patterns/ | Resaw if needed.
1.4 | wood | Inlay feature panel stock | 1 | sheet | 1/8 × 4 × 12 in (figured if available) | Hard maple | Bell Forest | 14 | 14 | buy | inlay-patterns/*/feature_constellation.dxf | Quilted/curly preferred.
1.5 | wood | Bird block stock | 1 | each | 1×1×10 in | Black walnut (1.1 offcut) | offcut | 0 | 0 | make | drawings/bird-block.svg (TBD) | Cut into 4 blocks (one per flute).
1.6 | wood | Drone block stock | 1 | each | 1.75×1.75×18 in | Black walnut | Hardwoods to Get | 15 | 15 | buy | drawings/drone-block.svg (TBD) | Yields 12 blocks: 3 per flute (U/5/8).
2.1 | hardware | Leather lacing | 4 | ft | 3/16 natural latigo | Leather | Tandy | 1.50 | 6 | buy | assembly-manual.md | Bird block tie.
2.2 | finish | Tru-Oil | 1 | bottle | 3 oz | Tung-oil/varnish blend | Brownells | 10 | 10 | buy | - | 4-6 coats.
2.3 | finish | Howards Feed-N-Wax | 1 | tin | 16 oz | Carnauba+orange oil | Hardware store | 10 | 10 | buy | - | Maintenance wax.
2.4 | consumables | Painter tape, 1 in | 1 | roll | 3M ScotchBlue | Crepe paper | Hardware store | 6 | 6 | buy | - | Mask glue squeezeout.
2.5 | consumables | Sandpaper assortment | 1 | pack | 120/180/220/320/400/600 | Aluminum oxide | Hardware store | 15 | 15 | buy | - | Final sand.
2.6 | consumables | Wood glue | 1 | bottle | Titebond II Premium 16 oz | PVA | Hardware store | 8 | 8 | buy | - | Body glue-up.
2.7 | consumables | CA glue, thin | 1 | bottle | Starbond EM-02 2 oz | Cyanoacrylate | Starbond | 10 | 10 | buy | - | Inlay set + stabilization.
2.8 | consumables | CA accelerator | 1 | bottle | Starbond NCF | Aerosol | Starbond | 8 | 8 | buy | - | Cure CA fast.
2.9 | consumables | Foam applicators | 20 | each | Tru-Oil application | Foam | Amazon | 0.25 | 5 | buy | - | Lint-free finish.
3.1 | tooling | 1/16 upcut spiral | 1 | each | 1/8 shank, 1/2 LOC | Solid carbide | IDC Woodcraft | 22 | 22 | buy | cnc/ | Inlay + splitting edge.
3.2 | tooling | 1/4 downcut spiral | 1 | each | 1/4 shank, 1 LOC | Solid carbide | IDC Woodcraft | 32 | 32 | buy | cnc/ | Bore + SAC.
3.3 | tooling | 1/2 downcut spiral | 1 | each | 1/2 shank, 1.25 LOC | Solid carbide | IDC Woodcraft | 45 | 45 | buy | cnc/ | Faceting pass.
3.4 | tooling | 3/4 ball end | 1 | each | 1/2 shank, 1.5 LOC | Solid carbide | IDC Woodcraft | 58 | 58 | buy | cnc/ | Optional 3D detail.
3.5 | tooling | Brad-point drills | 4 | each | 1/4, 9/32, 5/16, 11/32 | HSS | Lee Valley | 5.50 | 22 | buy | cnc/ | Tone holes.
3.6 | tooling | Forstner bits | 4 | each | 5/8, 3/4, 7/8, 1 in | HSS | Lee Valley | 12 | 48 | buy | cnc/ | Drone socket bores.
4.1 | files | CNC G-code, bore profile | 4 | file | one per key | - | self | 0 | 0 | make | cnc/ | Generated in V-Carve.
4.2 | files | CNC G-code, facet pass | 4 | file | one per key | - | self | 0 | 0 | make | cnc/ | -
4.3 | files | CNC G-code, inlay pocket | 12 | file | 3 bands × 4 keys | - | self | 0 | 0 | make | cnc/ | -
4.4 | files | CNC G-code, inlay plug | 12 | file | - | - | self | 0 | 0 | make | cnc/ | Cut from maple stock.
4.5 | files | CNC G-code, feature panel | 4 | file | pocket+plug | - | self | 0 | 0 | make | cnc/ | -
4.6 | files | CNC G-code, finger holes | 4 | file | six per flute | - | self | 0 | 0 | make | cnc/ | -

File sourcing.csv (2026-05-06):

part_no | search_terms | candidate_supplier | url | date_checked | unit_price_usd | min_order | lead_time_days | substitute_acceptable | sourcing_risk | notes
1.1 | black walnut S4S 1.5x1.5x26 lumber | Hardwoods to Get | hardwoodstogo.com | TBD | 22 | 1 | 7 | cherry, mahogany | low | Verify grain runout < 1:12.
1.2 | black walnut S4S 1.75x1.75x32 | Hardwoods to Get | hardwoodstogo.com | TBD | 30 | 1 | 7 | cherry, mahogany | low | Bigger blank for Em+Dm.
1.3 | hard maple thin stock 1/16 inch sheet | Bell Forest Products | bellforestproducts.com | TBD | 8 | 1 | 5 | curly maple, holly | low | Resaw if 1/16 unavailable.
1.4 | hard maple figured 1/8 inch board | Bell Forest Products | bellforestproducts.com | TBD | 14 | 1 | 5 | figured maple, birdseye maple | medium | Visual quality matters; pick personally if possible.
1.6 | black walnut 1.75x1.75 turning blank | Hardwoods to Get | hardwoodstogo.com | TBD | 15 | 1 | 7 | cherry, padauk | low | 12 drone blocks from one stick.
2.1 | natural latigo leather lacing 3/16 | Tandy Leather | tandyleather.com | TBD | 6 | 1 | 3 | rawhide, paracord | low | 4 ft serves all 4 flutes.
2.2 | birchwood casey tru-oil 3oz | Brownells / Amazon | amazon.com | TBD | 10 | 1 | 2 | Watco danish oil | low | Multiple coats; 4-6 builds gloss.
2.6 | titebond ii premium wood glue 16oz | Hardware store | - | TBD | 8 | 1 | 0 | Titebond III | low | Type II offers water resistance + reasonable open time.
2.7 | starbond em-02 thin ca glue 2oz | Starbond | starbond.com | TBD | 10 | 1 | 3 | Bob Smith Industries thin | low | Match accelerator brand.
3.1 | 1/16 inch upcut spiral 1/8 shank carbide | IDC Woodcraft | idcwoodcraft.com | TBD | 22 | 1 | 3 | Whiteside SCB-1 | low | Critical for clean inlay edges.
3.2 | 1/4 inch downcut spiral 1/4 shank carbide | IDC Woodcraft | idcwoodcraft.com | TBD | 32 | 1 | 3 | Whiteside RD-2160 | low | -
3.3 | 1/2 inch downcut spiral 1/2 shank carbide | IDC Woodcraft | idcwoodcraft.com | TBD | 45 | 1 | 3 | Whiteside RD-3300 | low | -
3.5 | brad point drill bits 1/4 9/32 5/16 11/32 | Lee Valley | leevalley.com | TBD | 5.50 | 4 | 5 | imperial drill set | low | Brad point reduces blowout.
3.6 | forstner bit 5/8 3/4 7/8 1 inch | Lee Valley | leevalley.com | TBD | 12 | 4 | 5 | sawtooth bit | low | Drone socket clean walls.

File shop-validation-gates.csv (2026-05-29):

gate_id | category | member_scope | claim | method | target | tolerance_or_limit | status | next_action | evidence
DXF-REV-001 | revision_authority | all | Acoustic body and drone-block DXF/CAD exports match the design workbook revision | document_review | All body/bore/tone-hole/drone-block/fixture exports name the same workbook revision and member configuration | pass_fail | blocked | Export or add reviewed CAD/DXF before acoustic CNC cutting | dxf-shop-authority.md
DXF-INLAY-002 | decorative_boundary | all | Decorative inlay DXFs are separated from acoustic and fit-critical authority | visual_register_review | Inlay assets are registered as decorative-only and not used for tuning bore hole socket or fixture geometry | pass_fail | pass | All inlay DXFs registered as concept_only in visual-output-register.csv; re-run check if assets change | visual-output-register.csv
TUNE-MEL-003 | drone_tuning | each_member | Melody fundamental and six holes tune within target after first article | tuner_log | fundamental m3 P4 P5 m6 m7 octave populated in validation.csv | +/- 5 cents after final trim | measurement_required | Build one member first and record measured Hz/cents before batch cutting | validation.csv
TUNE-DRN-004 | drone_tuning | each_member | Swappable drone blocks hold unison fifth-below and octave-below targets | tuner_log | drone-unison drone-fifth-below and drone-octave-below populated for each member | +/- 5 cents after final trim | measurement_required | Measure each block installed in its flute body and log cents error | validation.csv
BREATH-005 | breath_response | first_article | SAC window and bird setup speaks reliably across normal breath pressure | player_test_and_audio_log | stable tone onset without choking excessive hiss or delayed response | pass_fail | measurement_required | Record onset behavior breath notes and audio/video reference after first assembly | assembly-manual.md
BREATH-006 | breath_response | each_drone_mode | Drone block changes do not destabilize melody-side breath response | player_test_and_tuner_log | melody fundamental remains stable while each drone mode speaks | pass_fail | measurement_required | Test U 5 and 8 blocks with same body and bird setup | validation.csv
FAB-TENON-007 | fabrication_tolerance | all | Drone-block tenons meet slip-fit target without rattle or binding | caliper_and_go_no_go_fit | 0.005 in slip-fit clearance at 0.75 in engagement | +/- 0.003 in fit-critical | measurement_required | Turn scrap tenon and socket coupon before batch block turning | cut-list.csv
FAB-FACET-008 | fabrication_tolerance | all | Facet indexing supports inlay registration without shifting acoustic datum | scrap_or_first_article_check | facet datum repeats across eight rotations and inlay pockets stay centered | +/- 0.020 in pocket registration | measurement_required | Verify V-block stop and rotation indexing before cutting inlay pockets | dxf-shop-authority.md
FAB-BORE-009 | fabrication_tolerance | each_member | Split-body bore routing preserves bore ID and glue-line alignment | inspection_and_bore_gauge | bore ID and SAC/window geometry match reviewed DXF/CAD | TBD until CAD export | blocked | Add bore/tone-hole authority DXF/CAD and define inspection points | dxf-shop-authority.md

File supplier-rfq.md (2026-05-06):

# Supplier RFQ — Drone Flute Family

Three RFQ drafts: lumber yard, hardwood specialty, CNC tooling. Adapt names/dates/contact info before sending.

---

## RFQ 1 — Lumber yard (walnut S4S)

**Subject:** Quote request — Black walnut S4S blanks for instrument build

Hello,

I'm Tony Koop, an instrument maker working out of Maker Nexus in the South Bay. I'm building a set of four Native American style flutes and I need black walnut blanks, S4S, in the dimensions below. Quality requirements are unusual for this size: I need long-grain runout under 1:12 along the long axis, and minimal end-checking.

| Qty | Dimensions | Notes |
|---|---|---|
| 2 | 1.5 × 1.5 × 26 in | For F-key range flutes |
| 2 | 1.75 × 1.75 × 32 in | For lower-key flutes |
| 1 | 1.75 × 1.75 × 18 in | Drone block stock |

- Acceptable substitutions: rough-sawn at +0.10" oversize on each face is fine; I'll mill myself.
- Critical: straight grain along the LONG axis. End-grain runout > 1:12 = reject.
- Please include unit price, current stock level, lead time, and shipping to 95014.
- Quote good for 30 days appreciated.

Thanks,
Tony Koop
tonykoop@gmail.com

---

## RFQ 2 — Bell Forest Products (hard maple inlay stock)

**Subject:** Quote request — Hard maple thin stock for CNC inlay

Hello Bell Forest team,

I'm Tony Koop, building a set of drone flutes with CNC inlay panels in hard maple. I'm looking for two thicknesses of hard maple suitable for inlay work. Quilted or curly figure preferred for the feature panel; standard hard maple OK for the bands.

| Qty | Dimensions | Use | Notes |
|---|---|---|---|
| 2 | 1/16 × 2 × 24 in | Inlay band stock | Plain hard maple OK |
| 1 | 1/8 × 4 × 12 in | Feature panel | Quilted/curly preferred |

- Resaw is acceptable if 1/16" off-the-shelf is unavailable. I can pay a small surcharge.
- Critical: clean, dry stock at 6–8 % MC. No surface checking.
- Please include unit price, available figure grades for the feature panel piece, lead time, and shipping to 95014.

Thanks,
Tony Koop
tonykoop@gmail.com

---

## RFQ 3 — IDC Woodcraft (CNC router bits)

**Subject:** Quote — CNC bits for instrument-making project

Hi IDC,

Building a set of drone flutes; the bit list below covers four flutes worth of CNC operations on a ShopBot at Maker Nexus. Looking for production-grade carbide spirals.

| Qty | Bit | Spec |
|---|---|---|
| 1 | 1/16 upcut spiral | 1/8 shank, 1/2 LOC, solid carbide |
| 1 | 1/4 downcut spiral | 1/4 shank, 1 LOC, solid carbide |
| 1 | 1/2 downcut spiral | 1/2 shank, 1.25 LOC, solid carbide |
| 1 | 3/4 ball end | 1/2 shank, 1.5 LOC, solid carbide |

- Walnut + hard maple, both at typical hardness. No abrasive composites.
- Acceptable substitutions: any equivalent solid-carbide spiral; not interested in HSS or cobalt.
- Please confirm in-stock status, unit price, and standard shipping to 95014.

Thanks,
Tony Koop
tonykoop@gmail.com

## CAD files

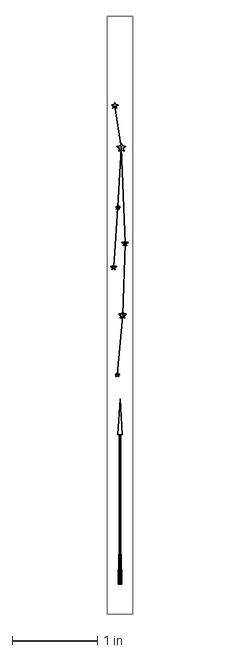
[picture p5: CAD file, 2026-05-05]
inlay-patterns/Am/feature_constellation.dxf
0.297 x 7.03 in

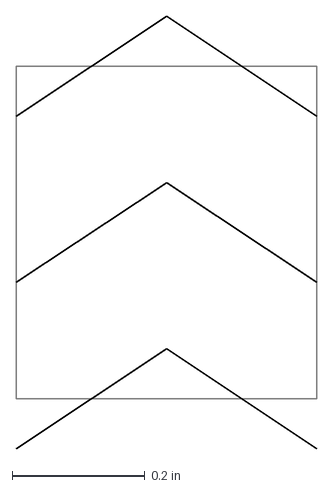
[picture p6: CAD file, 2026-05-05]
inlay-patterns/Dm/band2_chevron.dxf
0.452 x 0.65 in

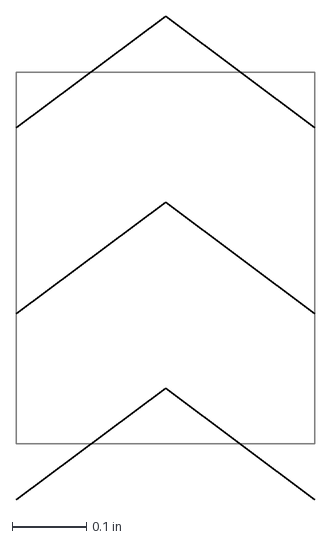
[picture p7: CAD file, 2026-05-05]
inlay-patterns/Em/band2_chevron.dxf
0.401 x 0.65 in

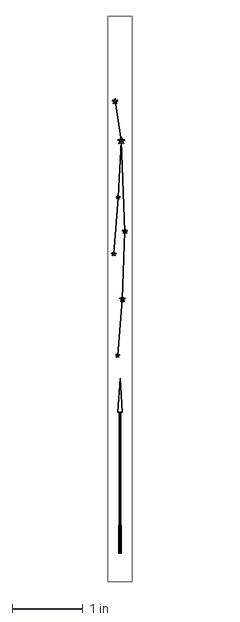
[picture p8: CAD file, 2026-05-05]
inlay-patterns/Fsharpm/feature_constellation.dxf
0.349 x 8.00 in

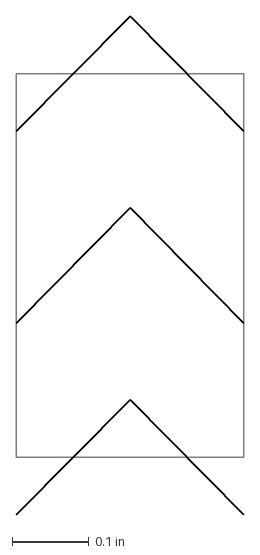
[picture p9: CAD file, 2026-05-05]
inlay-patterns/Am/band2_chevron.dxf
0.297 x 0.65 in

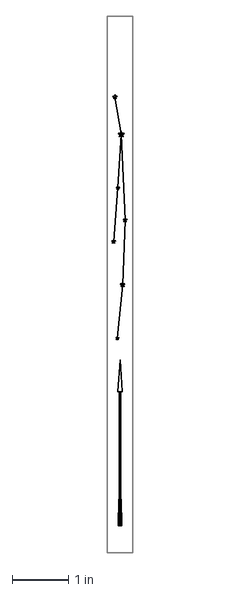
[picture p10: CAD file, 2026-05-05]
inlay-patterns/Dm/feature_constellation.dxf
0.452 x 9.54 in

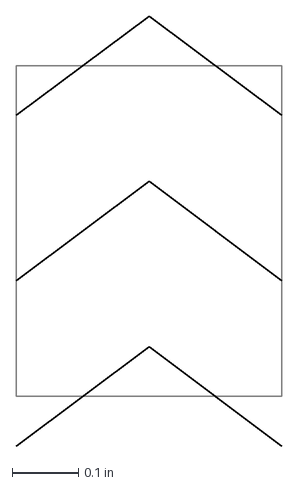
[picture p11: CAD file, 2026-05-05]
inlay-patterns/Em/band1_chevron.dxf
0.401 x 0.65 in

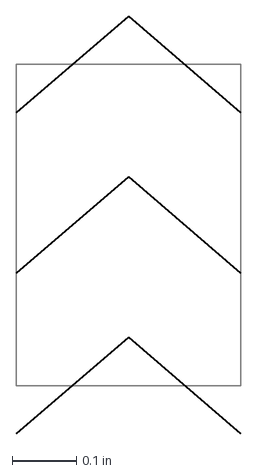
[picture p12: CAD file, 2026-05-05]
inlay-patterns/Fsharpm/band1_chevron.dxf
0.349 x 0.65 in

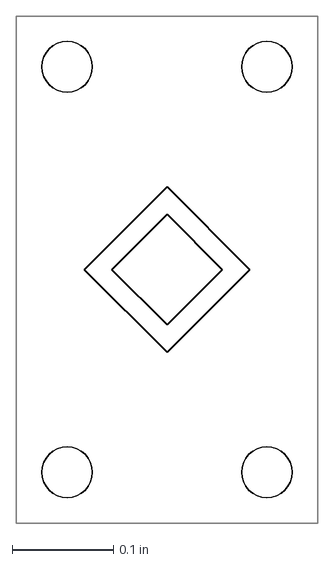
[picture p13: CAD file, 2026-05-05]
inlay-patterns/Am/band3_diamond.dxf
0.297 x 0.5 in

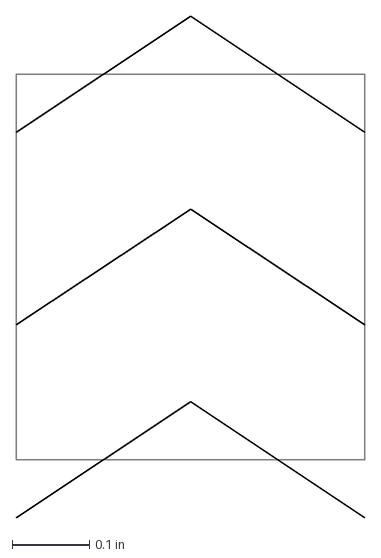
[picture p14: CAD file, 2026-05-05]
inlay-patterns/Dm/band1_chevron.dxf
0.452 x 0.65 in

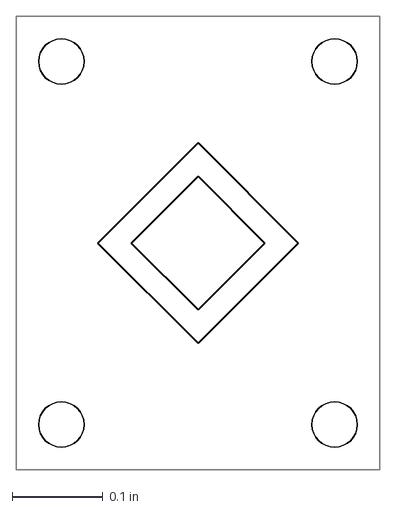
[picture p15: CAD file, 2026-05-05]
inlay-patterns/Em/band3_diamond.dxf
0.401 x 0.5 in

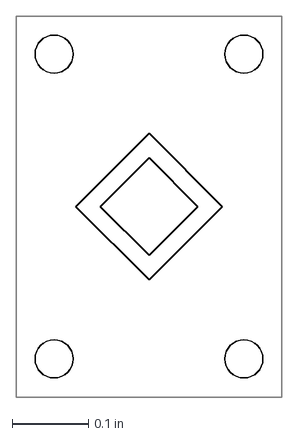
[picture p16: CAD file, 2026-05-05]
inlay-patterns/Fsharpm/band3_diamond.dxf
0.349 x 0.5 in

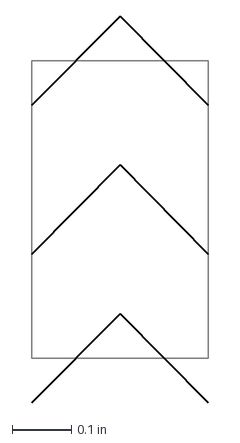
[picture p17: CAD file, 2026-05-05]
inlay-patterns/Am/band1_chevron.dxf
0.297 x 0.65 in

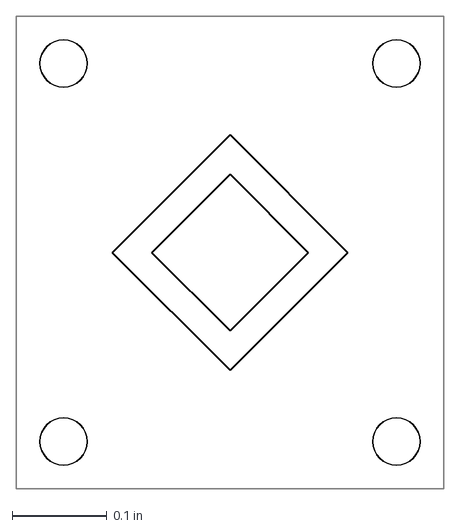
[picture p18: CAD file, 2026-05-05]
inlay-patterns/Dm/band3_diamond.dxf
0.452 x 0.5 in

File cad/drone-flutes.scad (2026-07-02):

// Drone Flute family — bore + tone-hole-schedule envelope master (DXF-first family).
//
// Authority: pending_measurement. NOT fabrication authority until reviewed
// (see visual-output-register.csv CAD-001 and cad/mcp-session-log.md).
// dxf-shop-authority.md still lists body/bore/tone-hole/drone-block DXF/CAD
// as "missing" — this .scad is the first parametric envelope, not a
// replacement for that reviewed export chain (DXF-REV-001, FAB-BORE-009
// remain blocked until a reviewed CAD/DXF revision is released).
//
// SCOPE / OUT OF SCOPE (Woodwind addendum, 2026-07-01):
//   In scope  — melody bore + drone-bore envelope diameters and lengths,
//               octagonal body facet envelope, and the six tone-hole
//               positions along the melody bore (equation-driven, like
//               fret slots).
//   Out of scope — duct/fipple geometry: SAC chamber, splitting-edge
//               (window) profile, bird-block/flue-gap voicing, undercutting
//               of tone holes, drone-socket tenon fit. These are exactly
//               the "hand-refined, tuning-sensitive" regions that must stay
//               hand-refined and are NOT modeled here. See dxf-shop-authority.md.
//
// Dimension sources (do not edit values without updating the source record):
//   - member_id / target_hz / bore_id_in / total_length_in / body_od_in /
//     facet_side_in / drone_bore_in: family-spec.csv (one row per member;
//     dimension_provenance = measurement_required for every row).
//   - governing acoustic model (open-open pipe + K2 bore correction) and
//     hole-position formula: design.md "Governing model" section, mirrored
//     in drone-flutes-starter.wl (source-only, not executed here).
//     f = c / (2*L_eff); L_eff = (c/(2*f0)) * (1 + K2(bore_id));
//     pos_from_foot = L_eff * (1 - f0/f_hole); pentatonic minor semitone
//     offsets [+3,+5,+7,+8,+10,+12] from the fundamental.
//   - facet geometry constants (facet_allowance, n_facets, wall thickness):
//     drone-flutes-starter.wl "Faceting" section, itself a mirror of
//     Drone-Flutes-Design.xlsx Master_Inputs — NOT independently re-derived
//     here, carried through as pending_measurement.
//   - tone-hole diameter per member: bom.csv row 3.5 ("Brad-point drills,
//     4 each, 1/4, 9/32, 5/16, 11/32 ... Tone holes"). ASSUMPTION: the four
//     bit sizes are read in ascending-bore order (Am->F#m->Em->Dm) since
//     bom.csv does not tag each size to a member; flag for review.
//   - melody-bore-to-drone-bore centerline offset: NOT present in
//     family-spec.csv, design.md, or the workbook mirror. TBD — exposed as
//     a top-level parameter (bore_offset_in) so it can be corrected in one
//     place once a reviewed value exists. Do NOT treat the placeholder as
//     fabrication authority.
//
// Units: inches.

/* [Family member] */
// 0=Am, 1=F#m, 2=Em, 3=Dm (family-spec.csv row order)
member = 0;

member_ids   = ["DRN-Am", "DRN-Fsm", "DRN-Em", "DRN-Dm"];
target_hz    = [440.000, 369.994, 329.628, 293.665];          // family-spec.csv target_hz
bore_id_in   = [0.750,   0.875,   1.000,   1.125];             // family-spec.csv bore_id_in
total_len_in = [21.967,  24.987,  27.225,  29.824];             // family-spec.csv total_length_in
body_od_in   = [1.300,   1.425,   1.550,   1.675];              // family-spec.csv body_od_in (round, pre-facet)
facet_side_in= [0.497,   0.549,   0.601,   0.652];              // family-spec.csv facet_side_in
drone_bore_in= [0.625,   0.750,   0.875,   1.000];              // family-spec.csv drone_bore_in

// bom.csv row 3.5 brad-point set, ascending-bore-order ASSUMPTION (ping for review).
tone_hole_dia_in = [0.250, 0.28125, 0.3125, 0.34375];

f0_hz          = target_hz[member];
bore_dia_in    = bore_id_in[member];
total_length_in= total_len_in[member];
body_dia_in    = body_od_in[member];
facet_side_len = facet_side_in[member];
drone_dia_in   = drone_bore_in[member];
hole_dia_in    = tone_hole_dia_in[member];

/* [Acoustic constants — design.md governing model] */
c_speed_of_sound_in_s = 13552; // in/s at 68 F, design.md
k_end                 = 0.6;   // open-end correction multiplier, design.md

/* [Faceting — drone-flutes-starter.wl mirror of workbook Master_Inputs] */
n_facets        = 8;     // octagon; workbook n_facets default
facet_allowance = 0.05;  // wl "Faceting" section
wall_in         = 0.25;  // wl per-member wall (same for all 4 members currently)

/* [Bore-to-bore offset — TBD, not in family-spec.csv or design.md] */
// ASSUMPTION placeholder only; do not fabricate from this value.
bore_offset_in = body_dia_in / 3;

/* [Pentatonic minor hole schedule — design.md] */
pentatonic_minor_semitones = [3, 5, 7, 8, 10, 12];

// ---------------------------------------------------------------------------
// Derived acoustic geometry (formulas, not baked values)
// ---------------------------------------------------------------------------

function k2_correction(bore_in) =
    bore_in <  0.750 ? -0.020 :
    bore_in <  0.875 ? -0.007 :
    bore_in <  1.000 ?  0.004 :
    bore_in <  1.125 ?  0.007 :
                         0.013;

function acoustic_length_in(f0, bore_in) =
    (c_speed_of_sound_in_s / (2 * f0)) * (1 + k2_correction(bore_in));

function hole_freq_hz(f0, semitone) = f0 * pow(2, semitone / 12);

function hole_pos_from_foot_in(f0, bore_in, semitone) =
    acoustic_length_in(f0, bore_in) * (1 - f0 / hole_freq_hz(f0, semitone));

// Regular-octagon circumradius from edge (facet) length.
function facet_circumradius_in(side_len) = side_len / (2 * sin(180 / n_facets));

// ---------------------------------------------------------------------------
// Modules
// ---------------------------------------------------------------------------

module melody_bore() {
  // Envelope only — no window/SAC/splitting-edge cut modeled (out of scope).
  rotate([0, 90, 0])
    cylinder(h = total_length_in, d = bore_dia_in, $fn = 64);
}

module drone_bore() {
  // Parallel envelope; length approximated at the shared body length since
  // the drone-block cavity length is a duct/voicing detail (out of scope).
  translate([0, bore_offset_in, 0])
    rotate([0, 90, 0])
      cylinder(h = total_length_in, d = drone_dia_in, $fn = 48);
}

module body_envelope_round() {
  // Pre-facet turned envelope, body_od_in from family-spec.csv.
  rotate([0, 90, 0])
    cylinder(h = total_length_in, d = body_dia_in, $fn = 96);
}

module body_envelope_facet() {
  // Reference-only octagon derived from facet_side_in; exact facet index/
  // rotation datum is a shop-jig concern (dxf-shop-authority.md
  // fixture-vblock-indexing.dxf), not modeled here.
  r = facet_circumradius_in(facet_side_len);
  rotate([0, 90, 0])
    cylinder(h = total_length_in, r = r, $fn = n_facets);
}

module tone_holes() {
  // Six pentatonic-minor holes, equation-driven positions from the foot
  // (x=0 = foot / open end). Radial placement on top of the bore only —
  // undercut/counterbore is out of scope (dxf-shop-authority.md).
  for (semitone = pentatonic_minor_semitones) {
    pos = hole_pos_from_foot_in(f0_hz, bore_dia_in, semitone);
    translate([pos, 0, bore_dia_in / 2])
      cylinder(h = wall_in * 3, d = hole_dia_in, center = true, $fn = 32);
  }
}

module drone_flute_assembly() {
  difference() {
    body_envelope_round();
    melody_bore();
    drone_bore();
    tone_holes();
  }
  // Faceted reference envelope shown as a translucent guide, offset above
  // the round body for comparison (not a cut/union — reference only).
  translate([0, 2 * body_dia_in, 0])
    body_envelope_facet();
}

drone_flute_assembly();

// Echo the hole schedule so `openscad` doubles as a position/frequency check.
echo(str("member=", member_ids[member], " f0_hz=", f0_hz,
         " L_acoustic_in=", acoustic_length_in(f0_hz, bore_dia_in)));
for (semitone = pentatonic_minor_semitones)
  echo(str("hole_semitone_", semitone,
           "_freq_hz=", hole_freq_hz(f0_hz, semitone),
           "_pos_from_foot_in=", hole_pos_from_foot_in(f0_hz, bore_dia_in, semitone)));

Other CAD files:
inlay-patterns/Em/feature_constellation.dxf
inlay-patterns/Fsharpm/band2_chevron.dxf

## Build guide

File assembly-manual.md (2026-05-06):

# Assembly Manual — Drone Flute Family

This manual is the shop-floor cheat sheet. For full context see `Drone-Flutes-BOM-Build-Method.docx`. For dimensional inputs see `Drone-Flutes-Design.xlsx`.

## Tools required

- ShopBot CNC router (Maker Nexus)
- Wood lathe (12 in swing minimum)
- Bandsaw (resaw the body blank)
- Drill press
- Epilog laser cutter (bird block engraving)
- Hand: chisels (1/4, 1/8), files (chainsaw + needle), calipers, square, marking gauge

## Safety

- Hearing protection during all power-tool ops.
- Dust mask (at minimum N95) when CNC routing walnut.
- Eye protection through entire build.
- Walnut dust is a known sensitizer; some people develop reactions over time. Run dust collection.

## Phase 1 — Stock prep

- [ ] Mill 4 walnut blanks to S4S per `cut-list.csv` (Am, F#m, Em, Dm).
- [ ] Verify grain runout ≤ 1:12 along the long axis. Reject and re-source if worse.
- [ ] Mark center reference line on each blank with marking gauge.
- [ ] Drill three 3/16" datum holes per blank (1" from each end + middle).
- [ ] **Acclimate 7 days minimum** before next phase.

## Phase 2 — Split-body CNC (bore + SAC)

- [ ] Bandsaw each blank exactly down centerline. Save kerf, hand-plane to glue surface.
- [ ] Match-mark each pair (left half / right half) with the key letter.
- [ ] Mount one half on CNC spoilboard with 3/16 dowels in datum holes + vacuum.
- [ ] Run **bore-profile pass** with 1/4 downcut spiral (cnc/{key}-bore.gcode). 18,000 rpm, 80 ipm, 0.25" per pass, 2 passes.
- [ ] Run **SAC pocket** pass with same bit (cnc/{key}-sac.gcode).
- [ ] Run **splitting-edge pass** with 1/16 upcut (cnc/{key}-window.gcode). Climb cut, single pass at 0.06" depth. Leave 0.005" skin — finish with chisel later.
- [ ] Flip second half onto same fixture, run mirrored G-code.
- [ ] Repeat for all 4 keys (8 halves total).

## Phase 3 — Glue-up

- [ ] Dry-fit each pair. If bore halves don't meet cleanly, lap mating faces on granite plate.
- [ ] Apply Titebond II thin and even to both faces.
- [ ] Clamp with 6+ clamps along the length, alternating top/bottom. Wax-paper between clamps and body.
- [ ] Use 3/16 dowels in datum holes during glue-up to hold alignment.
- [ ] Wait 24 h before unclamping.
- [ ] Inspect glue line. Repair gaps with thin CA + accelerator.

## Phase 4 — Lathe rounding

- [ ] Mount glued blank between centers (drive on foot, live on SAC end).
- [ ] Rough-turn round at ~800 rpm with 3/4 roughing gouge.
- [ ] Final-turn to **`body_OD_round`** from Design_Table for the active key. Leave 0.05" facet allowance.
- [ ] Sand on lathe to 220 grit while concentric.
- [ ] Pencil-mark a long reference line — this is the seam datum for faceting.

## Phase 5 — CNC faceting

- [ ] Build V-block jig: two MDF pieces at 22.5°, end-stops to lock axial position.
- [ ] Load 1/2 downcut spiral, 16,000 rpm, 120 ipm, 0.08" depth.
- [ ] Run pass 1: top facet. Verify with calipers (`body_OD_flat` from Excel).
- [ ] Rotate 45°, index using foot pin.
- [ ] Repeat 7 more times until all 8 facets are flat.

## Phase 6 — Tone hole drilling

- [ ] Mount body in horizontal jig with top facet up.
- [ ] Mark hole centers from `Hole_Schedule!{key}` sheet, measured from FOOT.
- [ ] Drill each hole through, with backer dowel inside bore to prevent blowout.
- [ ] Hole diameters per `Hole_Schedule!{key}_diameter`.
- [ ] Sand interior of each hole with rolled 320 grit.
- [ ] **Tune step:** play each note vs chromatic tuner, file foot-side edge to lower or fill bird-side edge with thin CA to raise.
- [ ] Once tuned, undercut the inside top edge of each hole at ~30° — this is the NAF "voice" undercut.

## Phase 7 — Window + splitting edge

- [ ] Plunge starting hole at splitting-edge location with 1/16 upcut.
- [ ] Cut window perimeter per `window_length × window_width` sketch.
- [ ] Shape the splitting edge with chisel + 320 grit. Edge should be knife-sharp.
- [ ] Test with light puff into SAC end. Clean tone? If breathy, sharpen edge. If too thin, glue veneer shim.

## Phase 8 — CNC inlay

- [ ] Place body back on V-block jig per facet.
- [ ] Load 1/16 upcut, 18,000 rpm, 60 ipm feed, 20 ipm plunge.
- [ ] Run **band1**, **band2**, **band3** pocket files for current facet (cnc/{key}-band[1-3]-pocket.gcode). 0.060" deep.
- [ ] Switch to maple stock fixture, run matching plug profile cuts at +0.001" oversize.
- [ ] Test fit. Sand plug underside if binding; thicker CA if loose.
- [ ] Apply thin CA, press plug into pocket, hit with accelerator.
- [ ] Repeat all 8 facets × 3 bands per flute = 24 inlay operations per flute, 96 total.
- [ ] **Feature panel:** pocket + plug pair on one chosen facet between band 2 and band 3, depth 0.080".
- [ ] Surface-sand body flat with 220 on flat block. Plugs sit flush.

## Phase 9 — Drone block set (3 per flute)

- [ ] Cut 12 walnut block blanks per `cut-list.csv` DRONE-x12.
- [ ] On lathe, turn each to body_OD with tenon at one end (tenon Ø = bore_ID − 0.005, length 0.75").
- [ ] Long-drill the drone bore from the foot end. Depth and diameter per Design_Table for that key + drone-offset combo:
  - Unison block: drone bore matches melody fundamental.
  - Fifth block: drone bore for fundamental × 2^(-7/12).
  - Octave block: drone bore for fundamental × 0.5 (longest cavity).
- [ ] Sand each block 320 grit.
- [ ] Engrave foot of each block on laser: U / 5 / 8.

## Phase 10 — Bird block (totem)

- [ ] Cut 4 walnut bird blanks (1×0.75×2 in).
- [ ] Laser-engrave the totem motif on each (eagle/wolf/bear/geometric — pick per flute personality).
- [ ] Cut shoulder on bottom matching top facet of body.
- [ ] Position over window. Verify flue gap 0.030–0.050".
- [ ] Sand bottom for tighter gap; veneer shim if too wide.

## Phase 11 — Finish

- [ ] Final sand body, drone blocks, bird blocks: 220 → 320 → 400 → 600.
- [ ] Wipe with tack cloth.
- [ ] Tru-Oil first coat (thin), 4–6 h dry.
- [ ] 600-grit sand between coats.
- [ ] 4–6 coats total.
- [ ] **Wait 7 days for full cure.**
- [ ] Buff with carnauba wax.

## Phase 12 — Final tuning + QA

- [ ] Tie bird block on with leather lacing.
- [ ] Insert unison drone block.
- [ ] Play pentatonic minor scale, tune each note with chromatic tuner. Record cents error in `validation.csv`.
- [ ] Swap to fifth, then octave drone blocks. Verify drone pitches.
- [ ] If any note > 5 cents off, adjust per Phase 6 tune step.
- [ ] Record video of all 4 flutes. Archive to `data/`.
- [ ] Photograph each finished flute against neutral background. Save to `images/`.

## Maintenance

- Reapply carnauba wax every few months.
- Avoid leaving in direct sun or near forced-air vents — humidity swings crack walnut.
- If a hole's tuning drifts, light file rather than CA fill (reversible).

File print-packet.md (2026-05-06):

# Drone Flute Family — Printable Shop Packet

Print this from the shop computer. Sections page-break for shop-floor reading.

---

## 1. Cover / Project Summary

**Project:** Drone Flute Family (DRN-FAM-001)
**Date:** 2026-05-05
**Builder:** Tony Koop
**Shop:** Maker Nexus, South Bay
**Materials cost:** $193 (walnut + maple) plus $245 one-time tooling = $438 first build, $193 every build after

A four-member family of Native American style drone flutes in keys Am, F#m, Em, Dm. Walnut bodies with hard-maple CNC inlay. Each flute has a separate drone chamber and ships with three swappable drone blocks (unison, fifth-below, octave-below).

---

## 2. Quick Start + File Map

1. Confirm walnut and maple stock are acclimated (7 days minimum).
2. Open `Drone-Flutes-Design.xlsx` — verify Master_Inputs match shop temp + concert pitch.
3. Open `cut-list.csv` — print and tape to the bandsaw.
4. Phase 1 (stock prep) → Phase 12 (tuning + photos) per `assembly-manual.md`.

Files in this packet:
- `Drone-Flutes-Design.xlsx` — source of truth
- `assembly-manual.md` — shop-floor build steps
- `cut-list.csv` — bandsaw + lathe cuts
- `bom.csv` — what to order
- `validation.csv` — tuning targets
- `drawings/` — per-key SVG drawings
- `inlay-patterns/` — DXFs for V-Carve
- `cnc/` — generated G-code (after CAM)
- `sw-reference/Drone-Flutes-SolidWorks-MasterLayout.docx` — CAD setup

---

## 3. Design Intent + Assumptions

- Open-open pipe physics with NAF K2 empirical correction.
- A=440 Hz concert pitch.
- 68°F shop reference temperature.
- Octagonal exterior (8 facets) for 8 inlay panels per body.
- Walnut is the body wood across all 4 flutes.
- Maple is the inlay wood across all 4 flutes.
- Drone offset is unison by default (matches melody fundamental).

Assumptions worth flagging:
- The K2 piecewise table is from 150+ NAF measurements on past flutes. New family, similar bore range — likely accurate within ±3 cents but verify on flute 1 before mass-finishing.
- Faceting allowance is 0.05"; this is conservative. If chatter on the lathe is bad, raise to 0.07".

---

## 4. BOM (paste of bom.csv with totals)

Wood subtotal: $193
Hardware + finish: $78
CNC tooling + drills (one-time): $245
Files: free

**Total first build: $516. Subsequent builds: $271.**

Full BOM in `bom.csv`. Print and bring to lumber yard / Bell Forest / IDC Woodcraft.

---

## 5. Sourcing List

See `sourcing.csv` for all suppliers + URLs + lead times. RFQ drafts in `supplier-rfq.md`.

---

## 6. Cut List + Stock Yield

See `cut-list.csv`. Highlights:
- 4 walnut body blanks (one per key, two sizes)
- 1 walnut block stick → 12 drone blocks (3 per flute × 4 flutes)
- 1 walnut offcut → 4 bird blocks
- 2 sheets 1/16" maple → all band inlay plugs
- 1 sheet 1/8" maple → all feature panel plugs

Yield: ~85% on bodies, ~95% on drone blocks, ~80% on inlay maple (lots of small pieces).

---

## 7. Drawings + Critical Dimensions

Drawings in `drawings/`:
- `Am.svg`, `Fsm.svg`, `Em.svg`, `Dm.svg` — per-key plan + section
- `assembly.svg` — exploded view (F#m canonical)
- `family-overview.svg` — all 4 to scale

**Critical tolerances:**
- Hole positions: ±0.020" (tuning-critical)
- Drone tenon: ±0.003" (fit-critical)
- Wall thickness at bore: ≥ 0.20" (structural minimum)
- Window splitting edge: knife-sharp (no measurement; listen-test)
- Inlay plug flush: < 0.005" proud or recessed
- Glue line: no visible gap

---

## 8. Assembly Manual

Full version in `assembly-manual.md`. Phase summary:

| Phase | Day | Focus |
|---|---|---|
| 1 | 1-7 | Stock prep + acclimation |
| 2 | 8-9 | Split-body CNC |
| 3 | 10 | Glue-up (24h cure) |
| 4 | 12 | Lathe rounding |
| 5 | 13 | CNC faceting |
| 6 | 14 | Tone holes + tune |
| 7 | 15 | Window + splitting edge |
| 8 | 16-22 | Inlay (24 ops/flute) |
| 9 | 23-24 | Drone blocks (12 total) |
| 10 | 25 | Bird blocks (4) |
| 11 | 26-31 | Finish (Tru-Oil 4-6 coats) |
| 12 | 38-42 | Cure + tune + photos |

---

## 9. Validation / Tuning Sheet

Predictions in `validation.csv`. Per-flute targets:

| Member | f0 (Hz) | h1 m3 | h2 P4 | h3 P5 | h4 m6 | h5 m7 | h6 oct |
|---|---|---|---|---|---|---|---|
| Am | 440.0 | 523.3 | 587.3 | 659.3 | 698.5 | 783.99 | 880.0 |
| F#m | 370.0 | 440.0 | 493.9 | 554.4 | 587.3 | 659.3 | 740.0 |
| Em | 329.6 | 392.0 | 440.0 | 493.9 | 523.3 | 587.3 | 659.3 |
| Dm | 293.7 | 349.2 | 392.0 | 440.0 | 466.2 | 523.3 | 587.3 |

Drone targets per flute = fundamental × {1, 2^(-7/12), 0.5} for the three blocks.

Tolerance: ±5 cents. Record measured Hz + cents error in `validation.csv`.

---

## 10. Supplier RFQ

Three RFQ drafts in `supplier-rfq.md`. Adapt the contact info and dates.

---

## 11. Visual BOM Brief

Layout spec in `visual-bom-brief.md`. Render `images/visual-bom.png` after photoshoot.

---

## 12. Appendix

- Raw formula reference: `wolfram-starter.wl`
- Capstone manifest: `capstone-manifest.json`
- Cross-references to sister repos: `flutes`, `fujara`, `transverse-flute`, `shakuhachi`
- This packet on the web: `site/index.html`
- License: see `LICENSE`

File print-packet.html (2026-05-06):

# 1 · Cover

Project: Drone Flute Family (DRN-FAM-001)
Date: 2026-05-05 Builder: Tony Koop Shop: Maker Nexus

Four NAF-style drone flutes (Am, F#m, Em, Dm), walnut + maple, tunable drone block set per flute (U/5/8).

Materials $193 · Tooling $245 (one-time) · Total first build $438+

# 2 · Quick Start

1. Confirm walnut + maple acclimated 7 days.
2. Open Drone-Flutes-Design.xlsx, verify Master_Inputs.
3. Print cut-list.csv, tape to bandsaw.
4. Phase 1 → Phase 12 per assembly-manual.md.

# 3 · Design Intent

- Open-open pipe + NAF K2 empirical correction
- A=440 Hz concert pitch
- 68°F reference temperature
- Octagonal body, 8 facets, walnut with hard-maple CNC inlay
- Drone offset = global var; flips all 4 flutes in one edit

# 4 · BOM Summary

Group | Subtotal
Wood | $193
Hardware + finish | $78
CNC tooling + drills | $245 (one-time)
Total first build | $516

Full BOM in bom.csv.

# 5 · Sourcing

See sourcing.csv for live URLs and lead times. RFQs ready in supplier-rfq.md.

# 6 · Cut List Highlights

- 4 walnut body blanks (Am+F#m: 1.5×1.5×26; Em+Dm: 1.75×1.75×32)
- 1 walnut stick → 12 drone blocks (3/flute × 4)
- 1 offcut → 4 bird blocks
- 2 sheets 1/16" maple + 1 sheet 1/8" maple → all inlay

# 7 · Drawings + Tolerances

Feature | Tolerance
Hole positions | ±0.020" (tuning-critical)
Drone tenon | ±0.003" (fit-critical)
Wall at bore | ≥ 0.20" (structural)
Splitting edge | knife-sharp (listen-test)
Inlay flush | < 0.005" proud/recessed

# 8 · Validation Targets

Member | f0 | m3 | P4 | P5 | m6 | m7 | oct
Am | 440.0 | 523.3 | 587.3 | 659.3 | 698.5 | 784.0 | 880.0
F#m | 370.0 | 440.0 | 493.9 | 554.4 | 587.3 | 659.3 | 740.0
Em | 329.6 | 392.0 | 440.0 | 493.9 | 523.3 | 587.3 | 659.3
Dm | 293.7 | 349.2 | 392.0 | 440.0 | 466.2 | 523.3 | 587.3

All values Hz. Tolerance ±5 cents. Record measured + cents-error in validation.csv.

# 9 · Shop Notes (write here)

Phase | Started | Done | Notes
1 — Stock prep | [ ] | [ ]
2 — Split-body CNC | [ ] | [ ]
3 — Glue-up | [ ] | [ ]
4 — Lathe | [ ] | [ ]
5 — Faceting | [ ] | [ ]
6 — Tone holes | [ ] | [ ]
7 — Window/edge | [ ] | [ ]
8 — Inlay | [ ] | [ ]
9 — Drone blocks | [ ] | [ ]
10 — Bird blocks | [ ] | [ ]
11 — Finish | [ ] | [ ]
12 — Tune + QA | [ ] | [ ]

# 10 · Risks Summary (top 3)

- A-1 · Hole 6 (octave) running sharp — listen during tune-step.
- A-2 · Drone-melody chamber leak — verify pre-glue + post-glue.
- E-1 · Em/Dm reach for 5th-percentile hands — measure before delivery.

Full red-team list in risks.md.

# Appendix · File Index

- Drone-Flutes-Design.xlsx — Excel design source
- design.md — physics narrative
- family-spec.csv — auto-generator input
- bom.csv · sourcing.csv · cut-list.csv · validation.csv
- assembly-manual.md · supplier-rfq.md · visual-bom-brief.md · drawing-brief.md
- risks.md — failure-mode walk
- wolfram-starter.wl — Wolfram package
- capstone-deck.pptx · capstone-deck.md
- print-packet.md · print-packet.html · print-packet.pdf
- capstone-manifest.json
- drawings/ — per-key SVGs
- inlay-patterns/ — 16 DXF + 16 SVG
- sw-reference/ — SolidWorks ref doc
- site/ — recruiter web page

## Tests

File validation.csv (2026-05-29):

member_id | note_id | target_hz | tolerance_cents | measured_hz | cents_error | tuner | environment | date | result | action
DRN-Am | fundamental | 440.000 | 5
DRN-Am | m3 | 523.251 | 5
DRN-Am | P4 | 587.330 | 5
DRN-Am | P5 | 659.255 | 5
DRN-Am | m6 | 698.456 | 5
DRN-Am | m7 | 783.991 | 5
DRN-Am | oct | 880.000 | 5
DRN-Am | drone-unison | 440.000 | 5
DRN-Am | drone-fifth-below | 293.665 | 5
DRN-Am | drone-octave-below | 220.000 | 5
DRN-Fsm | fundamental | 369.994 | 5
DRN-Fsm | m3 | 439.999 | 5
DRN-Fsm | P4 | 493.883 | 5
DRN-Fsm | P5 | 554.365 | 5
DRN-Fsm | m6 | 587.329 | 5
DRN-Fsm | m7 | 659.254 | 5
DRN-Fsm | oct | 739.988 | 5
DRN-Fsm | drone-unison | 369.994 | 5
DRN-Fsm | drone-fifth-below | 246.941 | 5
DRN-Fsm | drone-octave-below | 184.997 | 5
DRN-Em | fundamental | 329.628 | 5
DRN-Em | m3 | 391.996 | 5
DRN-Em | P4 | 440.001 | 5
DRN-Em | P5 | 493.884 | 5
DRN-Em | m6 | 523.252 | 5
DRN-Em | m7 | 587.330 | 5
DRN-Em | oct | 659.256 | 5
DRN-Em | drone-unison | 329.628 | 5
DRN-Em | drone-fifth-below | 220.000 | 5
DRN-Em | drone-octave-below | 164.814 | 5
DRN-Dm | fundamental | 293.665 | 5
DRN-Dm | m3 | 349.229 | 5
DRN-Dm | P4 | 391.996 | 5
DRN-Dm | P5 | 440.000 | 5
DRN-Dm | m6 | 466.164 | 5
DRN-Dm | m7 | 523.252 | 5
DRN-Dm | oct | 587.330 | 5
DRN-Dm | drone-unison | 293.665 | 5
DRN-Dm | drone-fifth-below | 195.998 | 5
DRN-Dm | drone-octave-below | 146.833 | 5
SHOP-AUTH | body-bore-dxf-revision |  |  |  |  |  |  | pending | Do not cut acoustic body geometry until body/bore/tone-hole/drone-block DXF or CAD exports are present and revision-matched to Drone-Flutes-Design.xlsx.
SHOP-AUTH | decorative-inlay-separation |  |  |  |  |  |  | pending | Keep inlay-patterns DXFs decorative-only; they do not control tuning bore hole socket or breath-response geometry.
SHOP-TUNE | drone-block-swap-response |  |  |  |  |  |  | measurement_required | Record unison fifth-below and octave-below drone response for each member before claiming validated drone tuning.
SHOP-BREATH | windway-sac-response |  |  |  |  |  |  | measurement_required | Record onset pressure breath noise choking overblow and stable tone behavior after SAC/window/bird fit is built.
SHOP-FAB | tenon-socket-slip-fit |  |  |  |  |  |  | measurement_required | Verify 0.005 in drone-block slip fit clearance with calipers and go/no-go feel before batch machining all blocks.
SHOP-FAB | body-facet-registration |  |  |  |  |  |  | measurement_required | Verify facet datum indexing and inlay pocket registration on scrap or first article before decorative inlay cutting.
DXF-AUTH | acoustic-body-dxf-gate |  |  |  |  |  |  | blocked | DXF-REV-001: acoustic body bore tone-hole socket and drone-block DXF/CAD exports are missing. Do not run CNC or lathe on acoustic geometry until reviewed exports match Drone-Flutes-Design.xlsx revision and pass dxf-shop-authority.md checklist.
DXF-AUTH | visual-register-status |  |  |  |  |  |  | pass | DXF-INLAY-002: all inlay DXFs registered as concept_only in visual-output-register.csv; print-packet.pdf registered as derived_preview.

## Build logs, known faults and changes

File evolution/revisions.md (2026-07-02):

# Revision Register — drone-flutes

| Rev | Date | Parent | Delta | Downstream artifacts invalidated |
| --- | --- | --- | --- | --- |
| A | 2026-07-01 | — | Stage 0 intake of current masters (cad/drone-flutes.scad + family-spec.csv + Drone-Flutes-Design.xlsx + drone-flutes-starter.wl). | none (no alpha/beta/production artifacts exist yet) |

Stage 0 only. Gate A has not been run; no Alpha compiles, vendor quotes, or production lock exist for this product. dxf-shop-authority.md's acoustic-body DXF/CAD gate (DXF-REV-001) remains blocked independent of this intake.

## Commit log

2026-05-05 claude instrument maker v4
    first v4 skill run
    [Drone-Flutes-Design.xlsx, band1_chevron.dxf, band2_chevron.dxf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]
2026-05-06 v4 update
    [bom.csv, cut-list.csv, family-spec.csv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]
2026-05-20 Add DXF shop authority gates (#3)
    [family-spec.csv, shop-validation-gates.csv, validation.csv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]
2026-05-29 Promote to L2 V5 DXF-first shop-handoff candidate (Refs #1) (#4)
    Updates README status to L2 V5 build-packet candidate; notes DXF-REV-001
    and FAB-BORE-009 remain blocked pending acoustic body/drone-block DXF exports.
    shop-validation-gates.csv: closes DXF-INLAY-002 as pass (all inlay DXFs
    registered concept_only in visual-output-register.csv).
    visual-output-register.csv: adds PDF-001 for print-packet.pdf as
    derived_preview with workbook authority noted.
    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
    [shop-validation-gates.csv, validation.csv, visual-output-register.csv]
2026-05-31 Add image-gen concept prompt; wire explorer images
2026-06-21 Wire 4 rendered concept image(s) into explorer gallery
2026-06-23 feat(wolfram): deploy interactive model + live explorer embed (#6)
    * feat(wolfram): deploy interactive model + live explorer embed
    CloudDeploy Manipulate to Wolfram Cloud (Public-Execute); regenerate
    explorer.html with live iframe. Refs tonykoop/instrument-maker#197
    * feat(wolfram): wire live explorer embed in explorer.html (Refs #197)
    ---------
2026-07-02 V5 packet refresh: status line, provenance, parametric OpenSCAD master, evolution intake
    - README status line fixed from broken **Status: L2 ...** to **Status:** L2
    V5 build-packet candidate (no promotion/demotion; DXF-first blockers kept
    in prose)
    - cad/drone-flutes.scad: new parametric bore + tone-hole-schedule envelope
    master (melody bore, drone bore, octagon body/facet envelope,
    equation-driven pentatonic-minor hole positions from design.md's governing
    model). No cad/ directory existed before this pass. Duct/fipple/window/
    voicing geometry explicitly out of scope per header. Renders clean in
    OpenSCAD for all 4 family members (Am/F#m/Em/Dm), authority
    pending_measurement.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
    [drone-flutes.scad, visual-output-register.csv]
